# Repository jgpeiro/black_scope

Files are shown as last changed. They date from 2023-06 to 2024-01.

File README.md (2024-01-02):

# Black_scope
Low end oscilloscope based on STM32G4
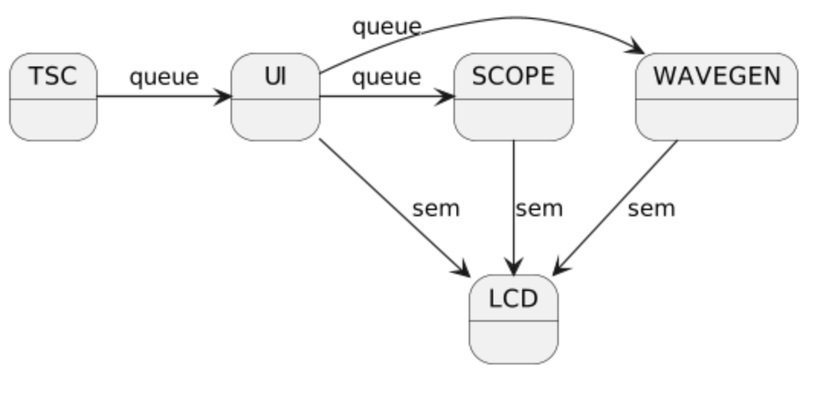
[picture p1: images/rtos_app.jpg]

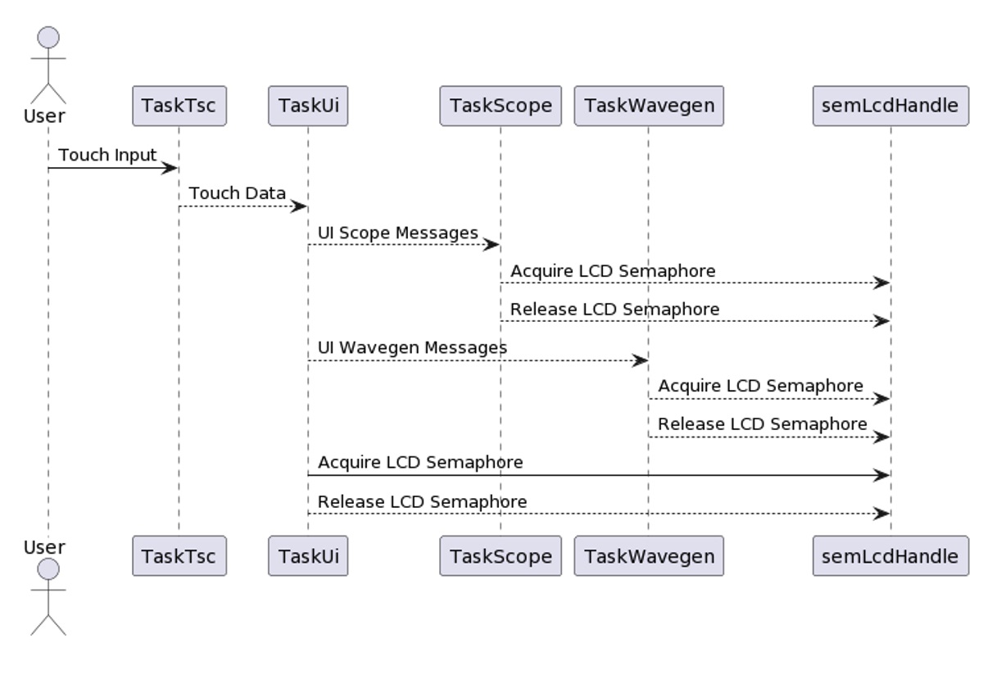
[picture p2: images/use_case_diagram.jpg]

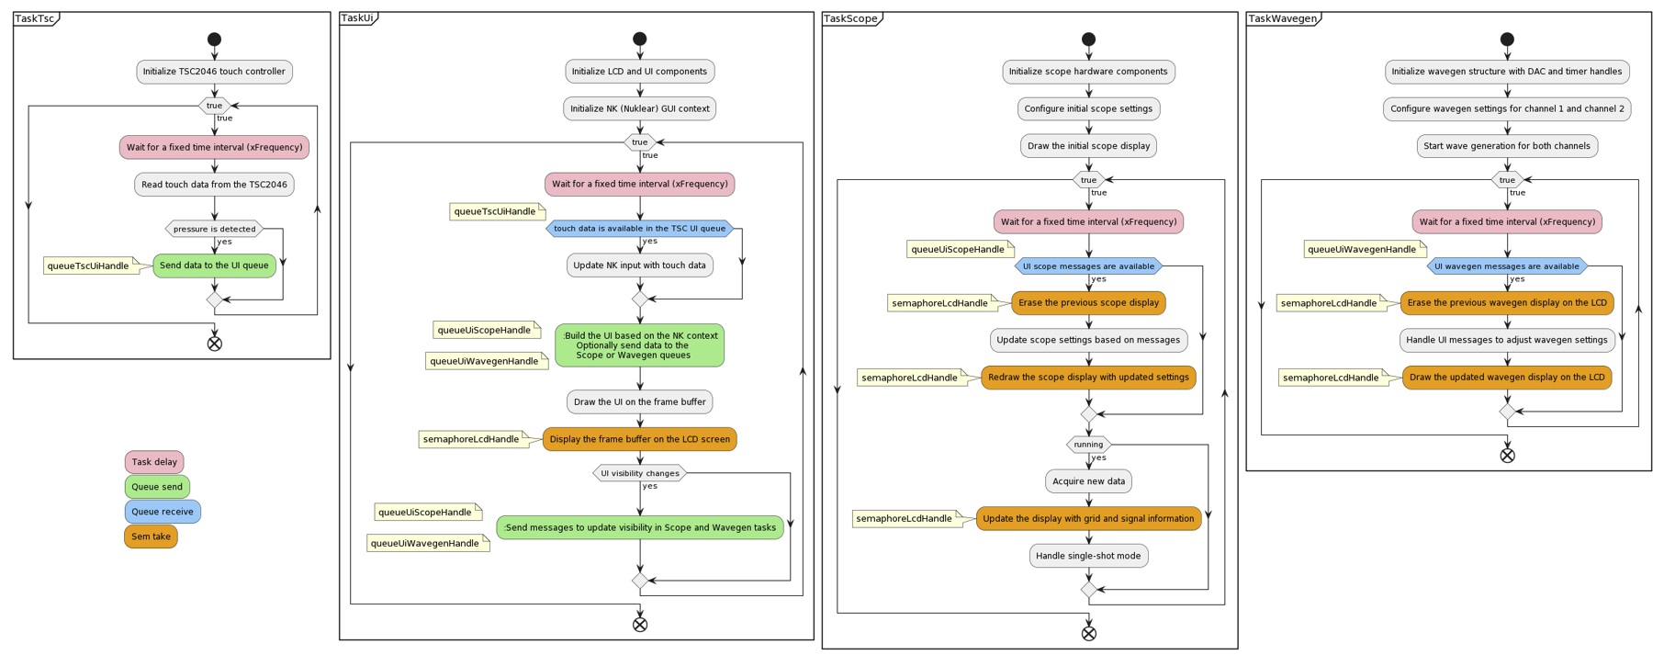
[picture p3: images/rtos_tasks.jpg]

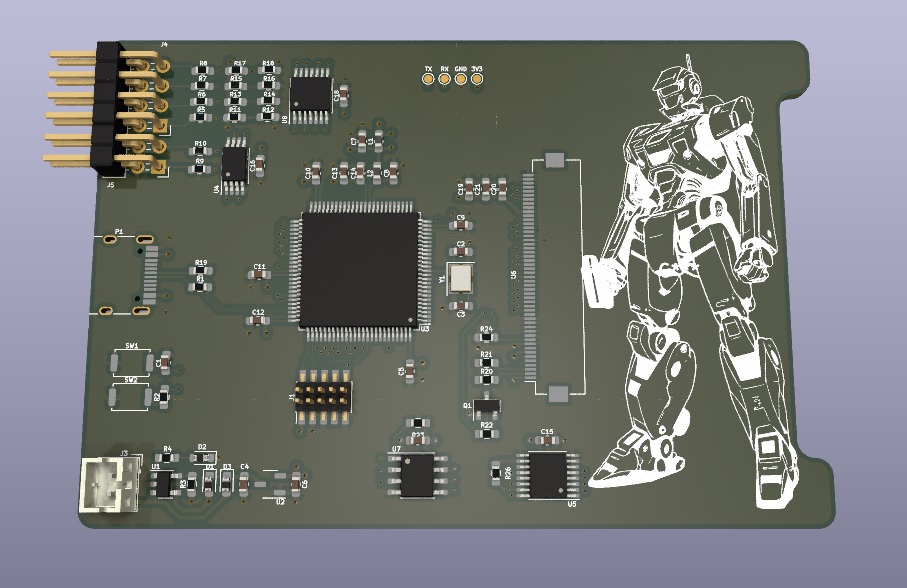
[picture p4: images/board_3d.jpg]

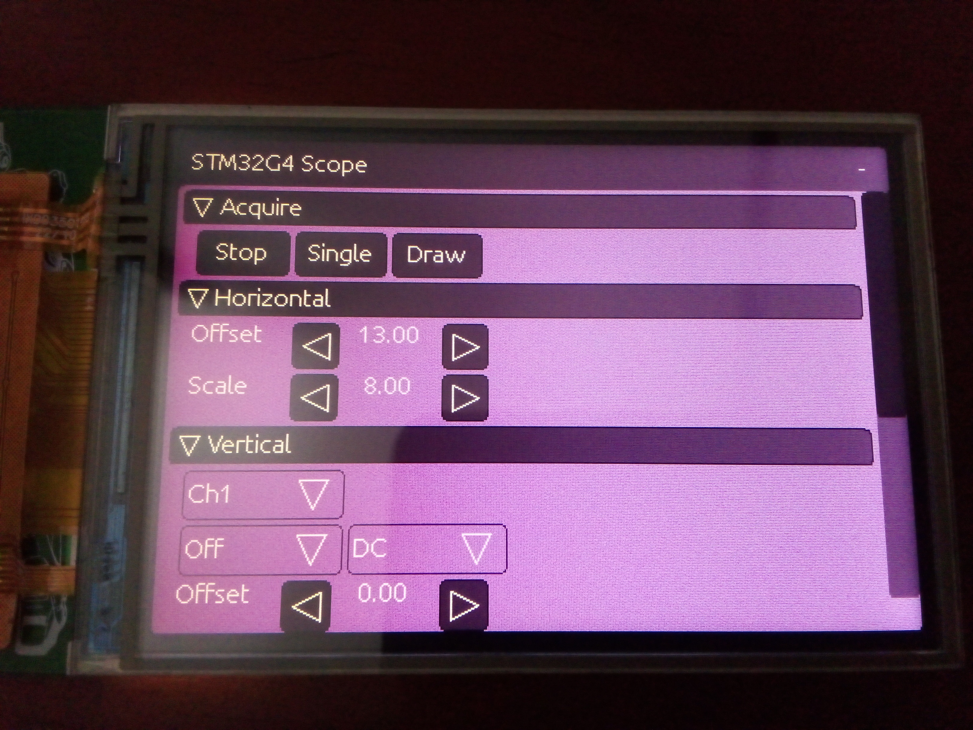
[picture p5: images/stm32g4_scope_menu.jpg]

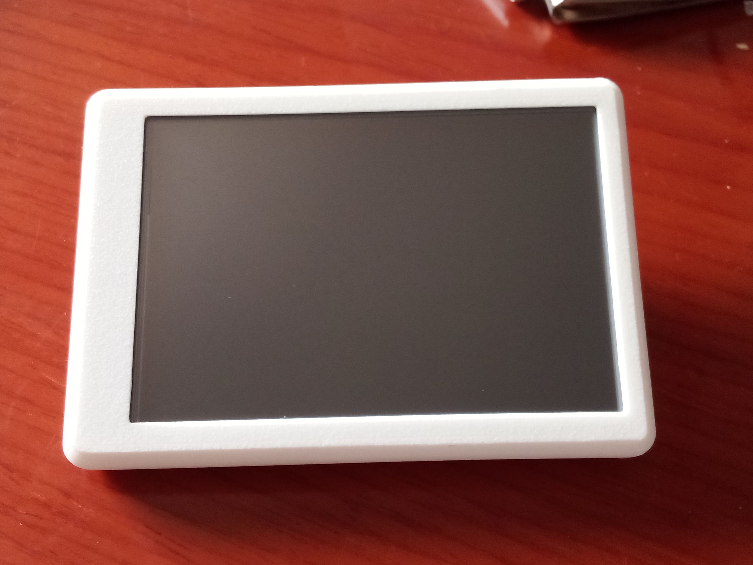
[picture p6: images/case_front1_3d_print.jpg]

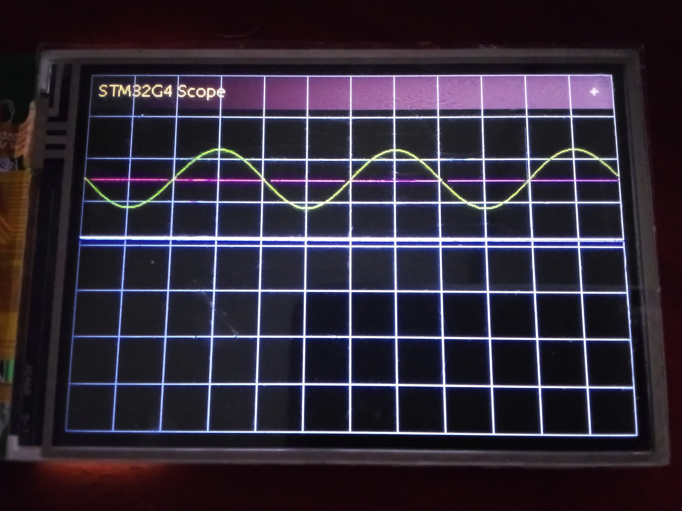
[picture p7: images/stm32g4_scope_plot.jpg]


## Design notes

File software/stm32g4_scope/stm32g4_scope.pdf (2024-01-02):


19/10/2023

stm32g4_scope Project
Configuration Report

## 1. Description

### 1.1. Project

Project Name | stm32g4_scope
Board Name | custom
Generated with: | STM32CubeMX 6.9.0
Date | 10/19/2023

### 1.2. MCU

MCU Series | STM32G4
MCU Line | STM32G4x3
MCU name | STM32G473VETx
MCU Package | LQFP100
MCU Pin number | 100

### 1.3. Core(s) information

Core(s) | ARM Cortex-M4

## 2. Pinout Configuration

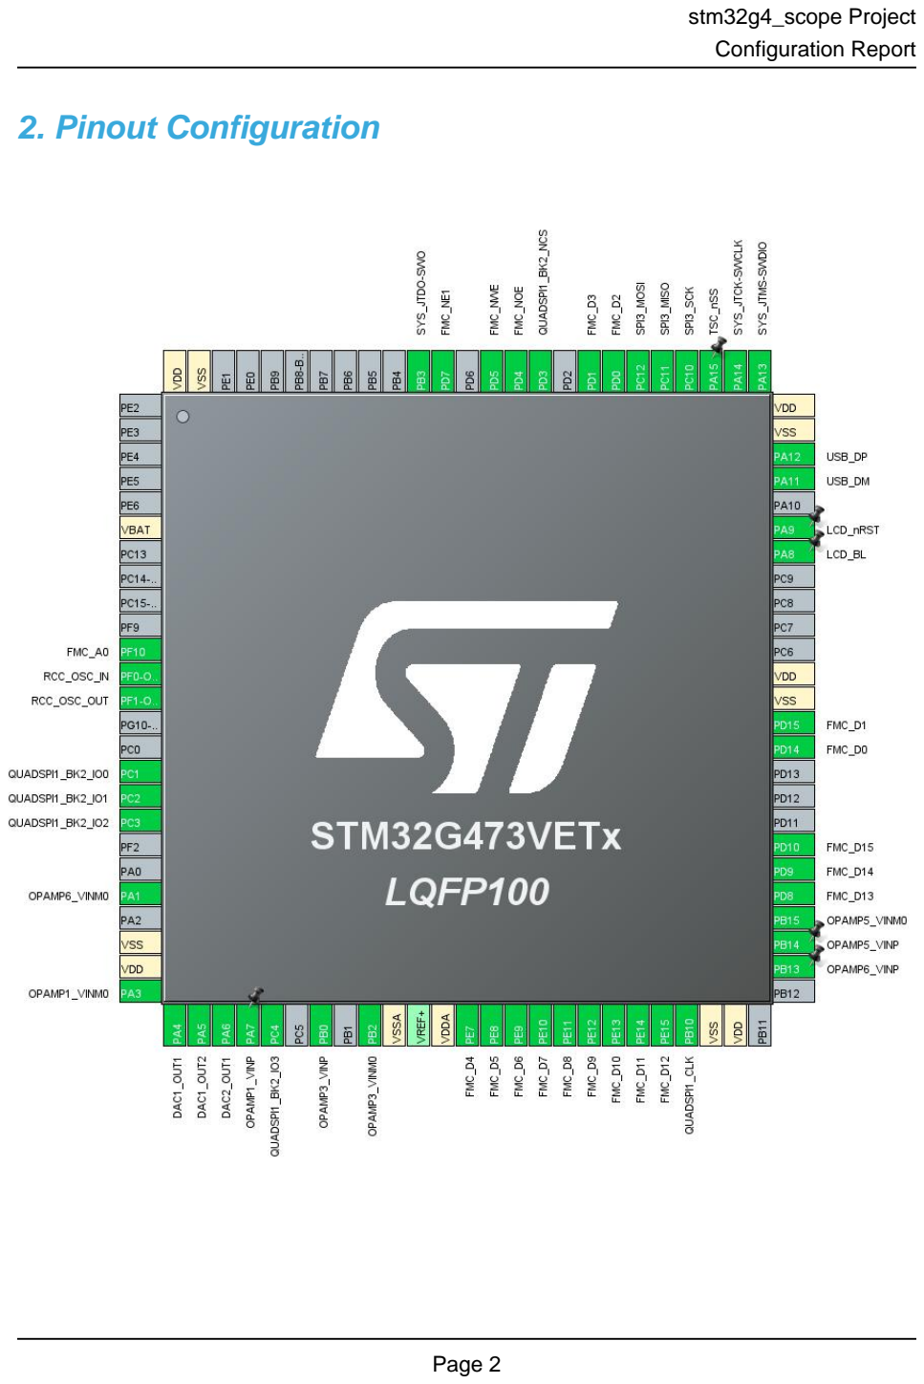
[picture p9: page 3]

## 3. Pins Configuration

Pin Number LQFP100 | Pin Name (function after reset) | Pin Type | Alternate Function(s) | Label
6 | VBAT | Power
11 | PF10 | I/O | FMC_A0
12 | PF0-OSC_IN | I/O | RCC_OSC_IN
13 | PF1-OSC_OUT | I/O | RCC_OSC_OUT
16 | PC1 | I/O | QUADSPI1_BK2_IO0
17 | PC2 | I/O | QUADSPI1_BK2_IO1
18 | PC3 | I/O | QUADSPI1_BK2_IO2
21 | PA1 | I/O | OPAMP6_VINM0
23 | VSS | Power
24 | VDD | Power
25 | PA3 | I/O | OPAMP1_VINM0
26 | PA4 | I/O | DAC1_OUT1
27 | PA5 | I/O | DAC1_OUT2
28 | PA6 | I/O | DAC2_OUT1
29 | PA7 | I/O | OPAMP1_VINP
30 | PC4 | I/O | QUADSPI1_BK2_IO3
32 | PB0 | I/O | OPAMP3_VINP
34 | PB2 | I/O | OPAMP3_VINM0
35 | VSSA | Power
37 | VDDA | Power
38 | PE7 | I/O | FMC_D4
39 | PE8 | I/O | FMC_D5
40 | PE9 | I/O | FMC_D6
41 | PE10 | I/O | FMC_D7
42 | PE11 | I/O | FMC_D8
43 | PE12 | I/O | FMC_D9
44 | PE13 | I/O | FMC_D10
45 | PE14 | I/O | FMC_D11
46 | PE15 | I/O | FMC_D12
47 | PB10 | I/O | QUADSPI1_CLK
48 | VSS | Power
49 | VDD | Power
52 | PB13 | I/O | OPAMP6_VINP
53 | PB14 | I/O | OPAMP5_VINP
54 | PB15 | I/O | OPAMP5_VINM0
55 | PD8 | I/O | FMC_D13

Pin Number LQFP100 | Pin Name (function after reset) | Pin Type | Alternate Function(s) | Label
56 | PD9 | I/O | FMC_D14
57 | PD10 | I/O | FMC_D15
61 | PD14 | I/O | FMC_D0
62 | PD15 | I/O | FMC_D1
63 | VSS | Power
64 | VDD | Power
69 | PA8 * | I/O | GPIO_Output | LCD_BL
70 | PA9 * | I/O | GPIO_Output | LCD_nRST
72 | PA11 | I/O | USB_DM
73 | PA12 | I/O | USB_DP
74 | VSS | Power
75 | VDD | Power
76 | PA13 | I/O | SYS_JTMS-SWDIO
77 | PA14 | I/O | SYS_JTCK-SWCLK
78 | PA15 * | I/O | GPIO_Output | TSC_nSS
79 | PC10 | I/O | SPI3_SCK
80 | PC11 | I/O | SPI3_MISO
81 | PC12 | I/O | SPI3_MOSI
82 | PD0 | I/O | FMC_D2
83 | PD1 | I/O | FMC_D3
85 | PD3 | I/O | QUADSPI1_BK2_NCS
86 | PD4 | I/O | FMC_NOE
87 | PD5 | I/O | FMC_NWE
89 | PD7 | I/O | FMC_NE1
90 | PB3 | I/O | SYS_JTDO-SWO
99 | VSS | Power
100 | VDD | Power

* The pin is affected with an I/O function

## 4. Clock Tree Configuration

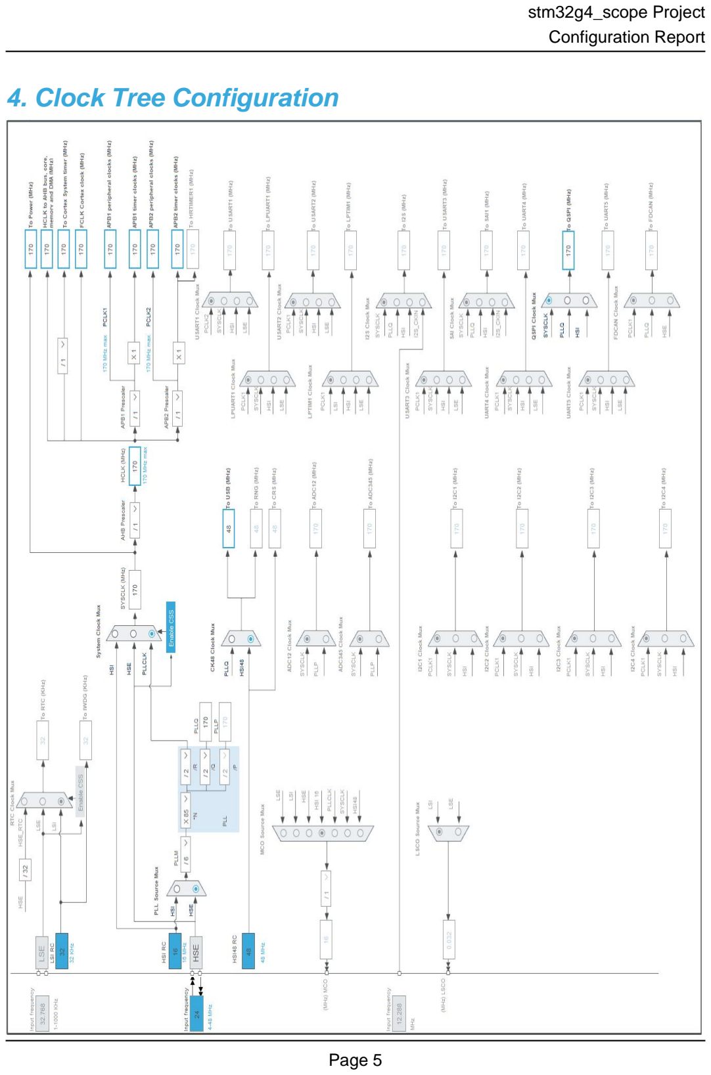
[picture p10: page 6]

## 5. Software Project

### 5.1. Project Settings

Name | Value
Project Name | stm32g4_scope
Project Folder | C:\git\black_scope\software\stm32g4_scope
Toolchain / IDE | STM32CubeIDE
Firmware Package Name and Version | STM32Cube FW_G4 V1.5.1
Application Structure | Advanced
Generate Under Root | Yes
Do not generate the main() | No
Minimum Heap Size | 0x200
Minimum Stack Size | 0x400

### 5.2. Code Generation Settings

Name | Value
STM32Cube MCU packages and embedded software | Copy only the necessary library files
Generate peripheral initialization as a pair of '.c/.h' files | Yes
Backup previously generated files when re-generating | No
Keep User Code when re-generating | Yes
Delete previously generated files when not re-generated | Yes
Set all free pins as analog (to optimize the power consumption) | No
Enable Full Assert | No

### 5.3. Advanced Settings - Generated Function Calls

Rank | Function Name | Peripheral Instance Name
1 | SystemClock_Config | RCC
2 | MX_GPIO_Init | GPIO
3 | MX_DMA_Init | DMA
4 | MX_ADC1_Init | ADC1
5 | MX_OPAMP1_Init | OPAMP1
6 | MX_DAC1_Init | DAC1
7 | MX_DAC2_Init | DAC2
8 | MX_TIM2_Init | TIM2
9 | MX_TIM3_Init | TIM3
10 | MX_FMC_Init | FMC
11 | MX_TIM4_Init | TIM4

Rank | Function Name | Peripheral Instance Name
12 | MX_ADC3_Init | ADC3
13 | MX_OPAMP3_Init | OPAMP3
14 | MX_OPAMP5_Init | OPAMP5
15 | MX_OPAMP6_Init | OPAMP6
16 | MX_ADC4_Init | ADC4
17 | MX_ADC5_Init | ADC5
18 | MX_SPI3_Init | SPI3
19 | MX_QUADSPI1_Init | QUADSPI1
20 | MX_TIM6_Init | TIM6
21 | MX_USB_Device_Init | USB_DEVICE

## 1. Power Consumption Calculator report

### 1.1. Microcontroller Selection

Series | STM32G4
Line | STM32G4x3
MCU | STM32G473VETx
Datasheet | DS12712_Rev0

### 1.2. Parameter Selection

Temperature | 25
Vdd | 3.0

### 1.3. Battery Selection

Battery | Li-SOCL2(A3400)
Capacity | 3400.0 mAh
Self Discharge | 0.08 %/month
Nominal Voltage | 3.6 V
Max Cont Current | 100.0 mA
Max Pulse Current | 200.0 mA
Cells in series | 1
Cells in parallel | 1

### 1.4. Sequence

Step | Step1 | Step2
Mode | RUN | STOP1
Vdd | 3.0 | 3.0
Voltage Source | Battery | Battery
Range | Range1-Boost | NoRange
Fetch Type | FLASH/DualBank/ART | NA
CPU Frequency | 170 MHz | 0 Hz
Clock Configuration | HSE BYP PLL | ALL CLOCKS OFF
Clock Source Frequency | 4 MHz | 0 Hz
Peripherals
Additional Cons. | 0 mA | 0 mA
Average Current | 29.5 mA | 80.5 µA
Duration | 0.1 ms | 0.9 ms
DMIPS | 213.0 | 0.0
Ta Max | 123.27 | 129.98
Category | In DS Table | In DS Table

### 1.5. Results

Sequence Time | 1 ms | Average Current | 3.02 mA
Battery Life | 1 month, 16 days, 9 hours | Average DMIPS | 212.5 DMIPS

### 1.6. Chart

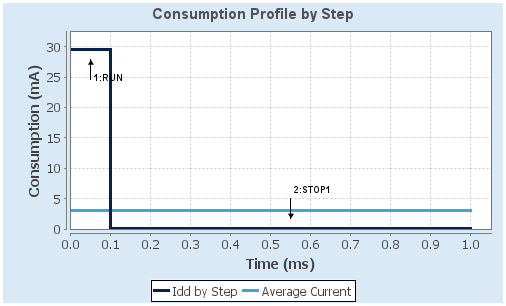
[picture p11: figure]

## 2. Peripherals and Middlewares Configuration

### 2.1. ADC1

mode: VOPAMP1 Channel
2.1.1. Parameter Settings:

ADCs_Common_Settings:

Mode | Independent mode
ADC_Settings:
Clock Prescaler | Synchronous clock mode divided by 4
Resolution | ADC 12-bit resolution
Data Alignment | Right alignment
Gain Compensation | 0
Scan Conversion Mode | Disabled
End Of Conversion Selection | End of single conversion
Low Power Auto Wait | Disabled
Continuous Conversion Mode | Disabled
Discontinuous Conversion Mode | Disabled
DMA Continuous Requests | Enabled *
Overrun behaviour | Overrun data preserved
ADC_Regular_ConversionMode:
Enable Regular Conversions | Enable
Enable Regular Oversampling | Disable
Number Of Conversion | 1
External Trigger Conversion Source | Timer 2 Trigger Out event *
External Trigger Conversion Edge | Trigger detection on the rising edge
Rank | 1
Channel | Channel Vopamp1
Sampling Time | 2.5 Cycles
Offset Number | No offset
Monitored by | Analog Watchdog 2 *
ADC_Injected_ConversionMode:
Enable Injected Conversions | Disable
Analog Watchdog 1:
Enable Analog WatchDog1 Mode | true *
Watchdog Mode | Single regular channel
Analog WatchDog Channel | Channel Vopamp1
High Threshold | 4095 *
Low Threshold | 2048+768 *
Interrupt Mode | Enabled *

Filtering | None
Analog Watchdog 2:
Enable Analog WatchDog2 Mode | true *
Watchdog Mode | Single channel *
High Threshold | 2048+768 *
Low Threshold | 0
Interrupt Mode | Enabled *
Analog Watchdog 3:
Enable Analog WatchDog3 Mode | false

### 2.2. ADC3

mode: VOPAMP3 Channel
2.2.1. Parameter Settings:

ADCs_Common_Settings:

Mode | Independent mode
ADC_Settings:
Clock Prescaler | Synchronous clock mode divided by 4
Resolution | ADC 12-bit resolution
Data Alignment | Right alignment
Gain Compensation | 0
Scan Conversion Mode | Disabled
End Of Conversion Selection | End of single conversion
Low Power Auto Wait | Disabled
Continuous Conversion Mode | Disabled
Discontinuous Conversion Mode | Disabled
DMA Continuous Requests | Enabled *
Overrun behaviour | Overrun data preserved
ADC_Regular_ConversionMode:
Enable Regular Conversions | Enable
Enable Regular Oversampling | Disable
Number Of Conversion | 1
External Trigger Conversion Source | Timer 2 Trigger Out event *
External Trigger Conversion Edge | Trigger detection on the rising edge
Rank | 1
Channel | Channel Vopamp3
Sampling Time | 2.5 Cycles
Offset Number | No offset
Monitored by

Analog Watchdog 2 *
ADC_Injected_ConversionMode:
Enable Injected Conversions | Disable
Analog Watchdog 1:
Enable Analog WatchDog1 Mode | true *
Watchdog Mode | Single regular channel
Analog WatchDog Channel | Channel Vopamp3
High Threshold | 0
Low Threshold | 0
Interrupt Mode | Enabled *
Filtering | None
Analog Watchdog 2:
Enable Analog WatchDog2 Mode | true *
Watchdog Mode | Single channel *
High Threshold | 0
Low Threshold | 0
Interrupt Mode | Enabled *
Analog Watchdog 3:
Enable Analog WatchDog3 Mode | false

### 2.3. ADC4

mode: VOPAMP6 Channel
2.3.1. Parameter Settings:

ADCs_Common_Settings:

Mode | Independent mode
ADC_Settings:
Clock Prescaler | Synchronous clock mode divided by 4
Resolution | ADC 12-bit resolution
Data Alignment | Right alignment
Gain Compensation | 0
Scan Conversion Mode | Disabled
End Of Conversion Selection | End of single conversion
Low Power Auto Wait | Disabled
Continuous Conversion Mode | Disabled
Discontinuous Conversion Mode | Disabled
DMA Continuous Requests | Enabled *
Overrun behaviour | Overrun data preserved

ADC_Regular_ConversionMode:

Enable Regular Conversions | Enable
Enable Regular Oversampling | Disable
Number Of Conversion | 1
External Trigger Conversion Source | Timer 2 Trigger Out event *
External Trigger Conversion Edge | Trigger detection on the rising edge
Rank | 1
Channel | Channel Vopamp6
Sampling Time | 2.5 Cycles
Offset Number | No offset
Monitored by | Analog Watchdog 2 *
ADC_Injected_ConversionMode:
Enable Injected Conversions | Disable
Analog Watchdog 1:
Enable Analog WatchDog1 Mode | true *
Watchdog Mode | Single regular channel
Analog WatchDog Channel | Channel Vopamp6
High Threshold | 0
Low Threshold | 0
Interrupt Mode | Enabled *
Filtering | None
Analog Watchdog 2:
Enable Analog WatchDog2 Mode | true *
Watchdog Mode | Single channel *
High Threshold | 0
Low Threshold | 0
Interrupt Mode | Enabled *
Analog Watchdog 3:
Enable Analog WatchDog3 Mode | false

### 2.4. ADC5

mode: VOPAMP5 Channel
2.4.1. Parameter Settings:

ADC_Settings:

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

Gain Compensation | 0
Scan Conversion Mode | Disabled
End Of Conversion Selection | End of single conversion
Low Power Auto Wait | Disabled
Continuous Conversion Mode | Disabled
Discontinuous Conversion Mode | Disabled
DMA Continuous Requests | Enabled *
Overrun behaviour | Overrun data preserved
ADC_Regular_ConversionMode:
Enable Regular Conversions | Enable
Enable Regular Oversampling | Disable
Number Of Conversion | 1
External Trigger Conversion Source | Timer 2 Trigger Out event *
External Trigger Conversion Edge | Trigger detection on the rising edge
Rank | 1
Channel | Channel Vopamp5
Sampling Time | 2.5 Cycles
Offset Number | No offset
Monitored by | Analog Watchdog 2 *
ADC_Injected_ConversionMode:
Enable Injected Conversions | Disable
Analog Watchdog 1:
Enable Analog WatchDog1 Mode | true *
Watchdog Mode | Single regular channel
Analog WatchDog Channel | Channel Vopamp5
High Threshold | 0
Low Threshold | 0
Interrupt Mode | Enabled *
Filtering | None
Analog Watchdog 2:
Enable Analog WatchDog2 Mode | true *
Watchdog Mode | Single channel *
High Threshold | 0
Low Threshold | 0
Interrupt Mode | Enabled *
Analog Watchdog 3:
Enable Analog WatchDog3 Mode | false

### 2.5. DAC1

OUT1 mode: Connected to external pin only OUT2 mode: Connected to external pin only
2.5.1. Parameter Settings:

DAC Out1 Settings:

Mode selected | Normal Mode
Output Buffer | Enable
DAC High Frequency | Mode Automatic
DMA Double Data | Disable
Signed Format | Disable
Trigger | Timer 4 Trigger Out event *
Trigger2 | None
Wave generation mode | Disabled
User Trimming | Factory trimming
DAC Out2 Settings:
Mode selected | Normal Mode
Output Buffer | Enable
DAC High Frequency | Mode Automatic
DMA Double Data | Disable
Signed Format | Disable
Trigger | Timer 6 Trigger Out event *
Trigger2 | None
Wave generation mode | Disabled
User Trimming | Factory trimming

### 2.6. DAC2

OUT1 mode: Connected to external pin only
2.6.1. Parameter Settings:

DAC Out1 Settings:

Mode selected | Normal Mode
Output Buffer | Enable
DAC High Frequency | Mode Automatic
DMA Double Data | Disable
Signed Format | Disable
Trigger | None
Trigger2 | None
User Trimming | Factory trimming

### 2.7. FMC

NOR Flash/PSRAM/SRAM/ROM/LCD 1 Chip Select: set
Memory type: LCD Interface
LCD Register Select: A0
Data: 16 bits
2.7.1. NOR/PSRAM 1:

NOR/PSRAM control:

Memory type | LCD Interface
Bank | Bank 1 NOR/PSRAM 1
Write operation | Enabled
Write FIFO | Enabled
Extended mode | Disabled
NOR/PSRAM timing:
Address setup time in HCLK clock cycles | 0 *
Data setup time in HCLK clock cycles | 1 *
Data hold time in HCLK clock cycles | 0
Bus turn around time in HCLK clock cycles | 0 *

### 2.8. OPAMP1

Mode: PGA Internally connected_IO0_BIAS
2.8.1. Parameter Settings:

Basic Parameters:

Power Mode | Normal
PGA Gain | 2 or -1
User Trimming | Disable

### 2.9. OPAMP3

Mode: PGA Internally connected_IO0_BIAS
2.9.1. Parameter Settings:

Basic Parameters:

Power Mode | Normal
PGA Gain | 2 or -1
User Trimming | Disable

### 2.10. OPAMP5

Mode: PGA Internally connected_IO0_BIAS
2.10.1. Parameter Settings:

Basic Parameters:

Power Mode | Normal
PGA Gain | 2 or -1
User Trimming | Disable

### 2.11. OPAMP6

Mode: PGA Internally connected_IO0_BIAS
2.11.1. Parameter Settings:

Basic Parameters:

Power Mode | Normal
PGA Gain | 2 or -1
User Trimming | Disable

### 2.12. QUADSPI1

QuadSPI Mode: Bank2 with Quad SPI Lines
2.12.1. Parameter Settings:

General Parameters:

Clock Prescaler | 6 *
Fifo Threshold | 1
Sample Shifting | No Sample Shifting
Flash Size | 23 *
Chip Select High Time | 1 Cycle
Clock Mode | Low

Flash ID | Flash ID 2
Dual Flash | Disabled

### 2.13. RCC

High Speed Clock (HSE): Crystal/Ceramic Resonator
2.13.1. Parameter Settings:

System Parameters:

VDD voltage (V) | 3.3
Instruction Cache | Enabled
Prefetch Buffer | Disabled
Data Cache | Enabled
Flash Latency(WS) | 4 WS (5 CPU cycle)
RCC Parameters:
HSI Calibration Value | 64
HSE Startup Timout Value (ms) | 100
LSE Startup Timout Value (ms) | 5000
Power Parameters:
Power Regulator Voltage Scale | Power Regulator Voltage Scale 1 boost
Peripherals Clock Configuration:
Generate the peripherals clock configuration | TRUE

### 2.14. SPI3

Mode: Full-Duplex Master
2.14.1. Parameter Settings:

Basic Parameters:

Frame Format | Motorola
Data Size | 8 Bits *
First Bit | MSB First
Clock Parameters:
Prescaler (for Baud Rate) | 128 *
Baud Rate | 1.328125 MBits/s *
Clock Polarity (CPOL) | Low
Clock Phase (CPHA) | 1 Edge
Advanced Parameters:
CRC Calculation | Disabled

NSSP Mode | Disabled *
NSS Signal Type | Software

### 2.15. SYS

Debug: Trace Asynchronous Sw
VREFBUF Mode: External voltage reference Timebase Source: TIM1

### 2.16. TIM2

Clock Source : Internal Clock
2.16.1. Parameter Settings:

Counter Settings:

Prescaler (PSC - 16 bits value) | 85-1 *
Counter Mode | Up
Dithering | Disable
Counter Period (AutoReload Register - 32 bits value ) | 2-1 *
Internal Clock Division (CKD) | No Division
auto-reload preload | Disable
Trigger Output (TRGO) Parameters:
Master/Slave Mode (MSM bit) | Disable (Trigger input effect not delayed)
Trigger Event Selection TRGO | Update Event *

### 2.17. TIM3

Clock Source : Internal Clock Channel1: Output Compare No Output
2.17.1. Parameter Settings:

Counter Settings:

Prescaler (PSC - 16 bits value) | 85-1 *
Counter Mode | Up
Dithering | Disable
Counter Period (AutoReload Register - 16 bits value ) | 512-1 *
Internal Clock Division (CKD) | No Division
auto-reload preload | Disable

Trigger Output (TRGO) Parameters:

Master/Slave Mode (MSM bit) | Disable (Trigger input effect not delayed)
Trigger Event Selection TRGO | Reset (UG bit from TIMx_EGR)
Clear Input:
Clear Input Source | Disable
Output Compare No Output Channel 1:
Mode | Frozen (used for Timing base)
Pulse (16 bits value) | 512-1 *
Output compare preload | Disable
CH Polarity | High

### 2.18. TIM4

Clock Source : Internal Clock
2.18.1. Parameter Settings:

Counter Settings:

Prescaler (PSC - 16 bits value) | 85-1 *
Counter Mode | Up
Dithering | Disable
Counter Period (AutoReload Register - 16 bits value ) | 2-1 *
Internal Clock Division (CKD) | No Division
auto-reload preload | Disable
Trigger Output (TRGO) Parameters:
Master/Slave Mode (MSM bit) | Disable (Trigger input effect not delayed)
Trigger Event Selection TRGO | Update Event *

### 2.19. TIM6

mode: Activated
2.19.1. Parameter Settings:

Counter Settings:

Prescaler (PSC - 16 bits value) | 85-1 *
Counter Mode | Up
Dithering | Disable
Counter Period (AutoReload Register - 16 bits value ) | 2-1 *
auto-reload preload | Disable

Trigger Output (TRGO) Parameters:

Trigger Event Selection | Update Event *

### 2.20. USB

mode: Device (FS)
2.20.1. Parameter Settings:

Basic Parameters:

Speed | Full Speed 12MBit/s
Physical interface | Internal Phy
Sof Enable | Disabled
Power Parameters:
Low Power | Disabled
Link Power Management | Disabled
Battery Charging | Disabled

### 2.21. FREERTOS

Interface: CMSIS_V2
2.21.1. Config parameters:

API:

FreeRTOS API | CMSIS v2
Versions:
FreeRTOS version | 10.3.1
CMSIS-RTOS version | 2.00
MPU/FPU:
ENABLE_MPU | Disabled
ENABLE_FPU | Disabled
Kernel settings:
USE_PREEMPTION | Enabled
CPU_CLOCK_HZ | SystemCoreClock
TICK_RATE_HZ | 1000
MAX_PRIORITIES | 56
MINIMAL_STACK_SIZE | 128
MAX_TASK_NAME_LEN | 16
USE_16_BIT_TICKS | Disabled
IDLE_SHOULD_YIELD | Enabled

USE_MUTEXES | Enabled
USE_RECURSIVE_MUTEXES | Enabled
USE_COUNTING_SEMAPHORES | Enabled
QUEUE_REGISTRY_SIZE | 8
USE_APPLICATION_TASK_TAG | Disabled
ENABLE_BACKWARD_COMPATIBILITY | Enabled
USE_PORT_OPTIMISED_TASK_SELECTION | Disabled
USE_TICKLESS_IDLE | Disabled
USE_TASK_NOTIFICATIONS | Enabled
RECORD_STACK_HIGH_ADDRESS | Disabled
Memory management settings:
Memory Allocation | Dynamic / Static
TOTAL_HEAP_SIZE | 16384 *
Memory Management scheme | heap_4
Hook function related definitions:
USE_IDLE_HOOK | Disabled
USE_TICK_HOOK | Disabled
USE_MALLOC_FAILED_HOOK | Disabled
USE_DAEMON_TASK_STARTUP_HOOK | Disabled
CHECK_FOR_STACK_OVERFLOW | Disabled
Run time and task stats gathering related definitions:
GENERATE_RUN_TIME_STATS | Disabled
USE_TRACE_FACILITY | Enabled
USE_STATS_FORMATTING_FUNCTIONS | Disabled
Co-routine related definitions:
USE_CO_ROUTINES | Disabled
MAX_CO_ROUTINE_PRIORITIES | 2
Software timer definitions:
USE_TIMERS | Enabled
TIMER_TASK_PRIORITY | 2
TIMER_QUEUE_LENGTH | 10
TIMER_TASK_STACK_DEPTH | 256
Interrupt nesting behaviour configuration:
LIBRARY_LOWEST_INTERRUPT_PRIORITY | 15
LIBRARY_MAX_SYSCALL_INTERRUPT_PRIORITY | 5
Added with 10.2.1 support:
MESSAGE_BUFFER_LENGTH_TYPE | size_t
USE_POSIX_ERRNO | Disabled
CMSIS-RTOS V2 flags:
USE_OS2_THREAD_SUSPEND_RESUME | Enabled
USE_OS2_THREAD_ENUMERATE | Enabled

USE_OS2_EVENTFLAGS_FROM_ISR | Enabled
USE_OS2_THREAD_FLAGS | Enabled
USE_OS2_TIMER | Enabled
USE_OS2_MUTEX | Enabled
2.21.2. Include parameters:

Include definitions:

vTaskPrioritySet | Enabled
uxTaskPriorityGet | Enabled
vTaskDelete | Enabled
vTaskCleanUpResources | Disabled
vTaskSuspend | Enabled
vTaskDelayUntil | Enabled
vTaskDelay | Enabled
xTaskGetSchedulerState | Enabled
xTaskResumeFromISR | Enabled
xQueueGetMutexHolder | Enabled
xSemaphoreGetMutexHolder | Disabled
pcTaskGetTaskName | Disabled
uxTaskGetStackHighWaterMark | Enabled
xTaskGetCurrentTaskHandle | Enabled
eTaskGetState | Enabled
xEventGroupSetBitFromISR | Disabled
xTimerPendFunctionCall | Enabled
xTaskAbortDelay | Disabled
xTaskGetHandle | Disabled
uxTaskGetStackHighWaterMark2 | Disabled
2.21.3. Advanced settings:

Newlib settings (see parameter description first):

USE_NEWLIB_REENTRANT | Enabled *
Project settings (see parameter description first):
Use FW pack heap file | Enabled

### 2.22. USB_DEVICE

Class For FS IP: Communication Device Class (Virtual Port Com)

2.22.1. Parameter Settings:

Basic Parameters:

USBD_MAX_NUM_INTERFACES (Maximum number of supported interfaces) | 1
USBD_MAX_NUM_CONFIGURATION (Maximum number of supported configuration) | 1
USBD_MAX_STR_DESC_SIZ (Maximum size for the string descriptors) | 512
USBD_SELF_POWERED (Enabled self power) | Enabled
USBD_DEBUG_LEVEL (USBD Debug Level) | 0: No debug message
USBD_LPM_ENABLED (Link Power Management) | 1: Link Power Management supported
Class Parameters:
USB CDC Rx Buffer Size | 2048
USB CDC Tx Buffer Size | 2048
2.22.2. Device Descriptor:

Device Descriptor:

VID (Vendor IDentifier) | 1155
LANGID_STRING (Language Identifier) | English(United States)
MANUFACTURER_STRING (Manufacturer Identifier) | STMicroelectronics
Device Descriptor FS:
PID (Product IDentifier) | 22336
PRODUCT_STRING (Product Identifier) | STM32 Virtual ComPort
CONFIGURATION_STRING (Configuration Identifier) | CDC Config
INTERFACE_STRING (Interface Identifier) | CDC Interface

* User modified value

## 3. System Configuration

### 3.1. GPIO configuration

IP | Pin | Signal | GPIO mode | GPIO pull/up pull down

Max
Speed

User Label

DAC1 | PA4 | DAC1_OUT1 | Analog mode | No pull-up and no pull-down | n/a
| PA5 | DAC1_OUT2 | Analog mode | No pull-up and no pull-down | n/a
DAC2 | PA6 | DAC2_OUT1 | Analog mode | No pull-up and no pull-down | n/a
FMC | PF10 | FMC_A0 | Alternate Function Push Pull | No pull-up and no pull-down | Very High
| PE7 | FMC_D4 | Alternate Function Push Pull | No pull-up and no pull-down | Very High
| PE8 | FMC_D5 | Alternate Function Push Pull | No pull-up and no pull-down | Very High
| PE9 | FMC_D6 | Alternate Function Push Pull | No pull-up and no pull-down | Very High
| PE10 | FMC_D7 | Alternate Function Push Pull | No pull-up and no pull-down | Very High
| PE11 | FMC_D8 | Alternate Function Push Pull | No pull-up and no pull-down | Very High
| PE12 | FMC_D9 | Alternate Function Push Pull | No pull-up and no pull-down | Very High
| PE13 | FMC_D10 | Alternate Function Push Pull | No pull-up and no pull-down | Very High
| PE14 | FMC_D11 | Alternate Function Push Pull | No pull-up and no pull-down | Very High
| PE15 | FMC_D12 | Alternate Function Push Pull | No pull-up and no pull-down | Very High
| PD8 | FMC_D13 | Alternate Function Push Pull | No pull-up and no pull-down | Very High
| PD9 | FMC_D14 | Alternate Function Push Pull | No pull-up and no pull-down | Very High
| PD10 | FMC_D15 | Alternate Function Push Pull | No pull-up and no pull-down | Very High
| PD14 | FMC_D0 | Alternate Function Push Pull | No pull-up and no pull-down | Very High
| PD15 | FMC_D1 | Alternate Function Push Pull | No pull-up and no pull-down | Very High
| PD0 | FMC_D2 | Alternate Function Push Pull | No pull-up and no pull-down | Very High
| PD1 | FMC_D3 | Alternate Function Push Pull | No pull-up and no pull-down | Very High
| PD4 | FMC_NOE | Alternate Function Push Pull | No pull-up and no pull-down | Very High
| PD5 | FMC_NWE | Alternate Function Push Pull | No pull-up and no pull-down | Very High
| PD7 | FMC_NE1 | Alternate Function Push Pull | No pull-up and no pull-down | Very High
OPAMP1 | PA3 | OPAMP1_VINM0 | Analog mode | No pull-up and no pull-down | n/a
| PA7 | OPAMP1_VINP | Analog mode | No pull-up and no pull-down | n/a
OPAMP3 | PB0 | OPAMP3_VINP | Analog mode | No pull-up and no pull-down | n/a
| PB2 | OPAMP3_VINM0 | Analog mode | No pull-up and no pull-down | n/a
OPAMP5 | PB14 | OPAMP5_VINP | Analog mode | No pull-up and no pull-down | n/a
| PB15 | OPAMP5_VINM0 | Analog mode | No pull-up and no pull-down | n/a
OPAMP6 | PA1 | OPAMP6_VINM0 | Analog mode | No pull-up and no pull-down | n/a
| PB13 | OPAMP6_VINP | Analog mode | No pull-up and no pull-down | n/a
QUADSPI1 | PC1 | QUADSPI1_BK2 _IO0 | Alternate Function Push Pull | No pull-up and no pull-down | Very High
*
| PC2 | QUADSPI1_BK2 _IO1 | Alternate Function Push Pull | No pull-up and no pull-down | Very High
*
| PC3 | QUADSPI1_BK2 | Alternate Function Push Pull | No pull-up and no pull-down | Very High

IP | Pin | Signal | GPIO mode | GPIO pull/up pull down | Max Speed | User Label
| | _IO2 | | | *
| PC4 | QUADSPI1_BK2 _IO3 | Alternate Function Push Pull | No pull-up and no pull-down | Very High *
| PB10 | QUADSPI1_CLK | Alternate Function Push Pull | No pull-up and no pull-down | Very High *
| PD3 | QUADSPI1_BK2 _NCS | Alternate Function Push Pull | No pull-up and no pull-down | Very High *
RCC | PF0-OSC_IN | RCC_OSC_IN | n/a | n/a | n/a
| PF1-OSC_OUT | RCC_OSC_OUT | n/a | n/a | n/a
SPI3 | PC10 | SPI3_SCK | Alternate Function Push Pull | No pull-up and no pull-down | Low
| PC11 | SPI3_MISO | Alternate Function Push Pull | No pull-up and no pull-down | Low
| PC12 | SPI3_MOSI | Alternate Function Push Pull | No pull-up and no pull-down | Low
SYS | PA13 | SYS_JTMS-SWDIO | n/a | n/a | n/a
| PA14 | SYS_JTCK-SWCLK | n/a | n/a | n/a
| PB3 | SYS_JTDO-SWO | n/a | n/a | n/a
USB | PA11 | USB_DM | n/a | n/a | n/a
| PA12 | USB_DP | n/a | n/a | n/a
GPIO | PA8 | GPIO_Output | Output Push Pull | No pull-up and no pull-down | Low | LCD_BL
| PA9 | GPIO_Output | Output Push Pull | No pull-up and no pull-down | Low | LCD_nRST
| PA15 | GPIO_Output | Output Push Pull | No pull-up and no pull-down | Low | TSC_nSS

### 3.2. DMA configuration

DMA request | Stream | Direction | Priority
ADC1 | DMA1_Channel1 | Peripheral To Memory | Low
DAC1_CH1 | DMA2_Channel1 | Memory To Peripheral | Low
ADC3 | DMA1_Channel2 | Peripheral To Memory | Low
ADC4 | DMA1_Channel3 | Peripheral To Memory | Low
ADC5 | DMA1_Channel4 | Peripheral To Memory | Low
DAC1_CH2 | DMA2_Channel2 | Memory To Peripheral | Low
QUADSPI | DMA1_Channel5 | Peripheral To Memory | Low

ADC1: DMA1_Channel1 DMA request Settings:

Mode: | Circular *
Peripheral Increment: | Disable
Memory Increment: | Enable *
Peripheral Data Width: | Half Word
Memory Data Width: | Half Word

DAC1_CH1: DMA2_Channel1 DMA request Settings:

Mode: | Circular *
Peripheral Increment: | Disable
Memory Increment: | Enable *
Peripheral Data Width: | Word *
Memory Data Width: | Half Word

ADC3: DMA1_Channel2 DMA request Settings:

Mode: | Circular *
Peripheral Increment: | Disable
Memory Increment: | Enable *
Peripheral Data Width: | Half Word
Memory Data Width: | Half Word

ADC4: DMA1_Channel3 DMA request Settings:

Mode: | Circular *

Peripheral Increment: | Disable
Memory Increment: | Enable *
Peripheral Data Width: | Half Word
Memory Data Width: | Half Word

ADC5: DMA1_Channel4 DMA request Settings:

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

DAC1_CH2: DMA2_Channel2 DMA request Settings:

Mode: | Circular *
Peripheral Increment: | Disable
Memory Increment: | Enable *
Peripheral Data Width: | Word *
Memory Data Width: | Half Word

QUADSPI: DMA1_Channel5 DMA request Settings:

Mode: | Normal
Peripheral Increment: | Disable
Memory Increment: | Enable *
Peripheral Data Width: | Byte
Memory Data Width: | Byte

### 3.3. NVIC configuration

3.3.1. NVIC
Interrupt Table | Enable | Preenmption Priority | SubPriority
Non maskable interrupt | true | 0 | 0
Hard fault interrupt | true | 0 | 0
Memory management fault | true | 0 | 0
Prefetch fault, memory access fault | true | 0 | 0
Undefined instruction or illegal state | true | 0 | 0
System service call via SWI instruction | true | 0 | 0
Debug monitor | true | 0 | 0
Pendable request for system service | true | 15 | 0
System tick timer | true | 15 | 0
DMA1 channel1 global interrupt | true | 5 | 0
DMA1 channel2 global interrupt | true | 5 | 0
DMA1 channel3 global interrupt | true | 5 | 0
DMA1 channel4 global interrupt | true | 5 | 0
DMA1 channel5 global interrupt | true | 5 | 0
ADC1 and ADC2 global interrupt | true | 5 | 0
USB low priority interrupt remap | true | 5 | 0
TIM1 update interrupt and TIM16 global interrupt | true | 15 | 0
TIM3 global interrupt | true | 5 | 0
ADC3 global interrupt | true | 5 | 0
DMA2 channel1 global interrupt | true | 5 | 0
DMA2 channel2 global interrupt | true | 5 | 0
ADC4 global interrupt | true | 5 | 0
ADC5 global interrupt | true | 5 | 0
QUADSPI global interrupt | true | 5 | 0
PVD/PVM1/PVM2/PVM3/PVM4 interrupts through EXTI lines 16/38/39/40/41 | unused
Flash global interrupt | unused
RCC global interrupt | unused
USB high priority interrupt remap | unused
TIM2 global interrupt | unused
TIM4 global interrupt | unused
SPI3 global interrupt | unused
TIM6 global interrupt, DAC1 and DAC3 channel underrun error interrupts | unused
TIM7 global interrupt, DAC2 and DAC4 channel underrun error interrupts | unused
FPU global interrupt | unused

3.3.2. NVIC Code generation
Enabled interrupt Table | Select for init sequence ordering | Generate IRQ handler | Call HAL handler
Non maskable interrupt | false | true | false
Hard fault interrupt | false | true | false
Memory management fault | false | true | false
Prefetch fault, memory access fault | false | true | false
Undefined instruction or illegal state | false | true | false
System service call via SWI instruction | false | false | false
Debug monitor | false | true | false
Pendable request for system service | false | false | false
System tick timer | false | false | true
DMA1 channel1 global interrupt | false | true | true
DMA1 channel2 global interrupt | false | true | true
DMA1 channel3 global interrupt | false | true | true
DMA1 channel4 global interrupt | false | true | true
DMA1 channel5 global interrupt | false | true | true
ADC1 and ADC2 global interrupt | false | true | true
USB low priority interrupt remap | false | true | true
TIM1 update interrupt and TIM16 global interrupt | false | true | true
TIM3 global interrupt | false | true | true
ADC3 global interrupt | false | true | true
DMA2 channel1 global interrupt | false | true | true
DMA2 channel2 global interrupt | false | true | true
ADC4 global interrupt | false | true | true
ADC5 global interrupt | false | true | true
QUADSPI global interrupt | false | true | true

* User modified value

## 4. System Views

4.1. Category view
4.1.1. Current

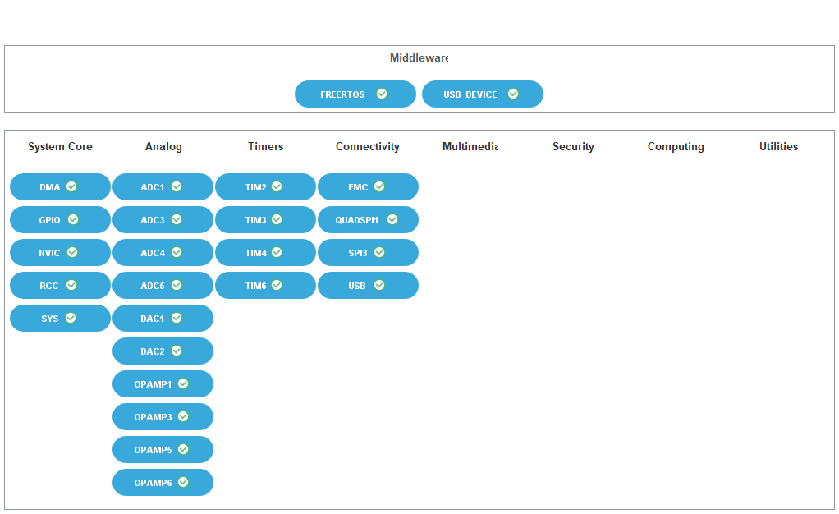
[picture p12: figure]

## 5. Docs & Resources

Type | Link
BSDL files | https://www.st.com/resource/en/bsdl_model/stm32g4_bsdl.zip
IBIS models | https://www.st.com/resource/en/ibis_model/stm32g4_ibis.zip
System View Description | https://www.st.com/resource/en/svd/stm32g4_svd.zip
Presentations | https://www.st.com/resource/en/product_presentation/microcontrollers_stm32g4_series_product_overview.pdf
Presentations | https://www.st.com/resource/en/product_presentation/stm32-stm8_embedded_software_solutions.pdf
Presentations | https://www.st.com/resource/en/product_presentation/stm32_eval-tools_portfolio.pdf
Presentations | https://www.st.com/resource/en/product_presentation/stm32_stm8_functi onal-safety-packages.pdf
Presentations | https://www.st.com/resource/en/product_presentation/stm32-usb-c-pd-solutions-presentation.pdf
Presentations | https://www.st.com/resource/en/product_presentation/stm32-stm8_software_development_tools.pdf
Brochures | https://www.st.com/resource/en/brochure/products-and-solutions-for-plcs-and-smart-i-os.pdf
Flyers | https://www.st.com/resource/en/flyer/flstm32g4.pdf
Flyers | https://www.st.com/resource/en/flyer/flstm32nucleo.pdf
Flyers | https://www.st.com/resource/en/flyer/flstm32trust.pdf
Flyers | https://www.st.com/resource/en/flyer/fldpstpfc11120.pdf
Application Notes | https://www.st.com/resource/en/application_note/an1181-electrostatic-discharge-sensitivity-measurement-stmicroelectronics.pdf
Application Notes | https://www.st.com/resource/en/application_note/an1709-emc-design-guide-for-stm8-stm32-and-legacy-mcus-stmicroelectronics.pdf
Application Notes | https://www.st.com/resource/en/application_note/an2606-stm32-microcontroller-system-memory-boot-mode-stmicroelectronics.pdf
Application Notes | https://www.st.com/resource/en/application_note/an2639-soldering-

| recommendations-and-package-information-for-leadfree-ecopack-mcus-and-mpus-stmicroelectronics.pdf
Application Notes | https://www.st.com/resource/en/application_note/an2834-how-to-get-the-best-adc-accuracy-in-stm32-microcontrollers-stmicroelectronics.pdf
Application Notes | https://www.st.com/resource/en/application_note/an3126-audio-and-waveform-generation-using-the-dac-in-stm32-products-stmicroelectronics.pdf
Application Notes | https://www.st.com/resource/en/application_note/an3155-usart-protocol-used-in-the-stm32-bootloader-stmicroelectronics.pdf
Application Notes | https://www.st.com/resource/en/application_note/an3156-usb-dfu-protocol-used-in-the-stm32-bootloader-stmicroelectronics.pdf
Application Notes | https://www.st.com/resource/en/application_note/an4013-stm32-crossseries-timer-overview-stmicroelectronics.pdf
Application Notes | https://www.st.com/resource/en/application_note/an4221-i2c-protocol-used-in-the-stm32-bootloader-stmicroelectronics.pdf
Application Notes | https://www.st.com/resource/en/application_note/an4229-how-to-implement-a-vocoder-solution-using-stm32-microcontrollers-stmicroelectronics.pdf
Application Notes | https://www.st.com/resource/en/application_note/an4232-getting-started-with-analog-comparators-for-stm32f3-series-and-stm32g4-series-devices-stmicroelectronics.pdf
Application Notes | https://www.st.com/resource/en/application_note/an4277-using-stm32-device-pwm-shutdown-features-for-motor-control-and-digital-power-conversion-stmicroelectronics.pdf
Application Notes | https://www.st.com/resource/en/application_note/an4286-spi-protocol-used-in-the-stm32-bootloader-stmicroelectronics.pdf
Application Notes | https://www.st.com/resource/en/application_note/an4296-use-stm32f3stm32g4-ccm-sram-with-iar-embedded-workbench-keil-mdkarm-stmicroelectronics-stm32cubeide-and-other-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
Application Notes | https://www.st.com/resource/en/application_note/an4566-extending-the-dac-performance-of-stm32-microcontrollers-stmicroelectronics.pdf
Application Notes | https://www.st.com/resource/en/application_note/an4635-minimization-of-

| power-consumption-using-lpuart-for-stm32-microcontrollers-stmicroelectronics.pdf
Application Notes | https://www.st.com/resource/en/application_note/an4655-virtually-increasing-the-number-of-serial-communication-peripherals-in-stm32-applications-stmicroelectronics.p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
Application Notes | https://www.st.com/resource/en/application_note/an4750-handling-of-soft-errors-in-stm32-applications-stmicroelectronics.pdf
Application Notes | https://www.st.com/resource/en/application_note/an4759-using-the-hardware-realtime-clock-rtc-and-the-tamper-management-unit-tamp-with-stm32-microcontrollers-stmicroe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
Application Notes | https://www.st.com/resource/en/application_note/an4776-generalpurpose-timer-cookbook-for-stm32-microcontrollers-stmicroelectronics.pdf
Application Notes | https://www.st.com/resource/en/application_note/an4803-highspeed-si-simulations-using-ibis-and-boardlevel-simulations-using-hyperlynx-si-on-stm32-mcus-and-mpus-stmic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
Application Notes | https://www.st.com/resource/en/application_note/an4894-eeprom-emulation-techniques-and-software-for-stm32-microcontrollers-stmicroelectronics.pdf
Application Notes | https://www.st.com/resource/en/application_note/an4989-stm32-microcontroller-debug-toolbox-stmicroelectronics.pdf
Application Notes | https://www.st.com/resource/en/application_note/an5027-interfacing-pdm-digital-microphones-using-stm32-mcus-and-mpus-stmicroelectronics.pdf
Application Notes | https://www.st.com/resource/en/application_note/an5036-thermal-management-guidelines-for-stm32-applications-stmicroelectronics.pdf
Application Notes | https://www.st.com/resource/en/application_note/an5093-getting-started-with-stm32g4-series--hardware-development-boards-stmicroelectronics.pdf
Application Notes | https://www.st.com/resource/en/application_note/an5224-stm32-dmamux-the-dma-request-router-stmicroelectronics.pdf
Application Notes | https://www.st.com/resource/en/application_note/an5225-usb-typec-power-delivery-using-stm32-mcus-and-mpus-stmicroelectronics.pdf
Application Notes | https://www.st.com/resource/en/application_note/an5306-operational-amplifier-opamp-usage-in-stm32g4-series-stmicroelectronics.pdf

Application Notes | https://www.st.com/resource/en/application_note/an5310-guideline-for-using-analog-features-of-stm32g4-series-versus-stm32f3-series-devices-stmicroelectronics.pdf
Application Notes | https://www.st.com/resource/en/application_note/an5315-stm32cube-firmware-examples-for-stm32g4-series-stmicroelectronics.pdf
Application Notes | https://www.st.com/resource/en/application_note/an5346-stm32g4-adc-use-tips-and-recommendations-stmicroelectronics.pdf
Application Notes | https://www.st.com/resource/en/application_note/an5405-fdcan-protocol-used-in-the-stm32-bootloader-stmicroelectronics.pdf
Application Notes | https://www.st.com/resource/en/application_note/an5543-enhanced-methods-to-handle-spi-communication-on-stm32-devices-stmicroelectronics.pdf
Application Notes | https://www.st.com/resource/en/application_note/an5690-vrefbuf-peripheral-applications-and-trimming-technique-stmicroelectronics.pdf
Application Notes | https://www.st.com/resource/en/application_note/an5738-stm32g4-series-lifetime-estimates-stmicroelectronics.pdf
Application Notes | https://www.st.com/resource/en/application_note/an4760-quadspi-interface-on-stm32-microcontrollers-and-microprocessors--stmicroelectronics.pdf
Application Notes | https://www.st.com/resource/en/application_note/an4899-stm32-microcontroller-gpio-hardware-settings-and-lowpower-consumption-stmicroelectronics.pdf
Application Notes | https://www.st.com/resource/en/application_note/an5612-esd-protection-of-stm32-mcus-and-mpus-stmicroelectronics.pdf
Application Notes | https://www.st.com/resource/en/application_note/an5156-introduction-to-stm32-microcontrollers-security-stmicroelectronics.pdf
Application Notes | https://www.st.com/resource/en/application_note/an2548-using-the-stm32f0f1f3cxgxlx-series-dma-controller-stmicroelectronics.pdf
Application Notes | https://www.st.com/resource/en/application_note/an4991-how-to-wake-up-an-stm32-microcontroller-from-lowpower-mode-with-the-usart-or-the-lpuart-stmicroelectronics.pdf
Application Notes | https://www.st.com/resource/en/application_note/an4838-introduction-to- memory-protection-unit-management-on-stm32-mcus-

| stmicroelectronics.pdf
Application Notes | https://www.st.com/resource/en/application_note/an5325-how-to-use-the-cordic-to-perform-mathematical-functions-on-stm32-mcus-stmicroelectronics.pdf
Application Notes | https://www.st.com/resource/en/application_note/an5348-introduction-to-fdcan-peripherals-for-stm32-product-classes-stmicroelectronics.pdf
Application Notes | https://www.st.com/resource/en/application_note/an4230-random-number-generation-validation-using-nist-statistical-test-suite-for-stm32-microcontrollers-stmicroelectr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
Application Notes for related Tools & Software | https://www.st.com/resource/en/application_note/an1202_freertos_guide-freertos-guide-stmicroelectronics.pdf
Application Notes for related Tools & Software | https://www.st.com/resource/en/application_note/an1602_semihosting_in_truestudio-how-to-do-semihosting-in-truestudio-stmicroelectronics.pdf
Application Notes for related Tools & Software | https://www.st.com/resource/en/application_note/an1801_stm32cubeprogrammer_in_truestudio-installing-stm32cubeprogrammer-in-truestudio-stmicroelectronics.pdf
Application Notes for related Tools & Software | https://www.st.com/resource/en/application_note/atollic_editing_keyboard_shortcuts-atollic-editing-keyboard-shortcuts-stmicroelectronics.pdf
Application Notes for related Tools & Software | https://www.st.com/resource/en/application_note/iar_to_atollic_truestudio_migration_guide-truestudio-for-arm-migration-guide-iar-embedded-workbench-to-truestudio-stm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
Application Notes for related Tools & Software | https://www.st.com/resource/en/application_note/stm32cubemx_installation_in_truestudio-stm32cubemx-installation-in-truestudio-stmicroelectronics.pdf
Application Notes for related Tools & Software | https://www.st.com/resource/en/application_note/an4435-guidelines-for-obtaining-ulcsaiec-607301603351-class-b-certification-in-any-stm32-application-stmicroelectroni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
Application Notes for related Tools & Software | https://www.st.com/resource/en/application_note/an4635-minimization-of-power-consumption-using-lpuart-for-stm32-microcontrollers-stmicroelectronics.pdf
Application Notes | https://www.st.com/resource/en/application_note/an4657-stm32-

for related Tools & Software | inapplication-programming-iap-using-the-usart-stmicroelectronics.pdf
Application Notes for related Tools & Software | https://www.st.com/resource/en/application_note/an4759-using-the-hardware-realtime-clock-rtc-and-the-tamper-management-unit-tamp-with-stm32-microcontrollers-stmicroe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
Application Notes for related Tools & Software | https://www.st.com/resource/en/application_note/an4841-digital-signal-processing-for-stm32-microcontrollers-using-cmsis-stmicroelectronics.pdf
Application Notes for related Tools & Software | https://www.st.com/resource/en/application_note/an5054-secure-programming-using-stm32cubeprogrammer-stmicroelectronics.pdf
Application Notes for related Tools & Software | https://www.st.com/resource/en/application_note/an5056-integration-guide-for-the-xcubesbsfu-stm32cube-expansion-package-stmicroelectronics.pdf
Application Notes for related Tools & Software | https://www.st.com/resource/en/application_note/an5305-digital-filter-implementation-with-the-fmac-using-stm32cubeg4-mcu-package-stmicroelectronics.pdf
Application Notes for related Tools & Software | https://www.st.com/resource/en/application_note/an5315-stm32cube-firmware-examples-for-stm32g4-series-stmicroelectronics.pdf
Application Notes for related Tools & Software | https://www.st.com/resource/en/application_note/an5345-highbrightness-rgb-led-control-using-the-bg474edpow1-discovery-kit-stmicroelectronics.pdf
Application Notes for related Tools & Software | https://www.st.com/resource/en/application_note/an5360-getting-started-with-projects-based-on-the-stm32mp1-series-in-stm32cubeide-stmicroelectronics.pdf
Application Notes for related Tools & Software | https://www.st.com/resource/en/application_note/an5361-getting-started-with-projects-based-on-dualcore-stm32h7-microcontrollers-in-stm32cubeide-stmicroelectronics.pd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
Application Notes for related Tools & Software | https://www.st.com/resource/en/application_note/an5394-getting-started-with-projects-based-on-the-stm32l5-series-in-stm32cubeide-stmicroelectronics.pdf

Application Notes
for related Tools

https://www.st.com/resource/en/application_note/an5418-how-to-build-asimple-usbpd-sink-application-with-stm32cubemx-stmicroelectronics.pdf

& Software
Application Notes for related Tools & Software | https://www.st.com/resource/en/application_note/an5426-migrating-graphics-middleware-projects-from-stm32cubemx-540-to-stm32cubemx-550-stmicroelectronics.pdf
Application Notes for related Tools & Software | https://www.st.com/resource/en/application_note/an5464-position-control-of-a-threephase-permanent-magnet-motor-using-xcubemcsdk-or-xcubemcsdkful-stmicroelectronics.p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
Application Notes for related Tools & Software | https://www.st.com/resource/en/application_note/an5496-buck-voltage-mode-with-the-bg474edpow1-discovery-kit-stmicroelectronics.pdf
Application Notes for related Tools & Software | https://www.st.com/resource/en/application_note/an5497-buck-current-mode-with-the-bg474edpow1-discovery-kit-stmicroelectronics.pdf
Application Notes for related Tools & Software | https://www.st.com/resource/en/application_note/an5564-getting-started-with-projects-based-on-dualcore-stm32wl-microcontrollers-in-stm32cubeide-stmicroelectronics.pd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
Application Notes for related Tools & Software | https://www.st.com/resource/en/application_note/an5698-adapting-the-xcubestl-functional-safety-package-for-stm32-iec-61508-compliant-to-other-safety-standards-stmicr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
Application Notes for related Tools & Software | https://www.st.com/resource/en/application_note/an5731-stm32cubemx-and-stm32cubeide-threadsafe-solution-stmicroelectronics.pdf
Application Notes for related Tools & Software | https://www.st.com/resource/en/application_note/an5785-boost-voltage-mode-on-bg474edpow1-discovery-kit-stmicroelectronics.pdf
Application Notes for related Tools & Software | https://www.st.com/resource/en/application_note/an5788-stm32-digital-power-pid-and-iir-filters-for-smps-control-design-and-comparison-on-bg414edpow1-discovery-kit-st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
Application Notes for related Tools & Software | https://www.st.com/resource/en/application_note/an4502-stm32-smbuspmbus-expansion-package-for-stm32cube-stmicroelectronics.pdf
Errata Sheets | https://www.st.com/resource/en/errata_sheet/es0430-stm32g471xx473xx474xx483xx484xx-device-errata-stmicroelectronics.pdf
Datasheet | https://www.st.com/resource/en/datasheet/dm00528822.pdf

Programming Manuals | https://www.st.com/resource/en/programming_manual/pm0214-stm32-cortexm4-mcus-and-mpus-programming-manual-stmicroelectronics.pdf
Reference Manuals | https://www.st.com/resource/en/reference_manual/rm0440-stm32g4-series-advanced-armbased-32bit-mcus-stmicroelectronics.pdf
Technical Notes & Articles | https://www.st.com/resource/en/technical_note/tn1163-description-of-wlcsp-for-microcontrollers-and-recommendations-for-its-use-stmicroelectronics.pdf
Technical Notes & Articles | https://www.st.com/resource/en/technical_note/tn1204-tape-and-reel-shipping-media-for-stm32-microcontrollers-in-bga-packages-stmicroelectronics.pdf
Technical Notes & Articles | https://www.st.com/resource/en/technical_note/tn1205-tape-and-reel-shipping-media-for-stm8-and-stm32-microcontrollers-in-fpn-packages-stmicroelectronics.pdf
Technical Notes & Articles | https://www.st.com/resource/en/technical_note/tn1206-tape-and-reel-shipping-media-for-stm8-and-stm32-microcontrollers-in-qfp-packages-stmicroelectronics.pdf
Technical Notes & Articles | https://www.st.com/resource/en/technical_note/tn1207-tape-and-reel-shipping-media-for-stm8-and-stm32-microcontrollers-in-so-packages-stmicroelectronics.pdf
Technical Notes & Articles | https://www.st.com/resource/en/technical_note/tn1208-tape-and-reel-shipping-media-for-stm8-and-stm32-microcontrollers-in-tssop-and-ssop-packages-stmicroelectronics.p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
Technical Notes & Articles | https://www.st.com/resource/en/technical_note/tn1433-reference-device-marking-schematics-for-stm32-microcontrollers-and-microprocessors-stmicroelectronics.pdf

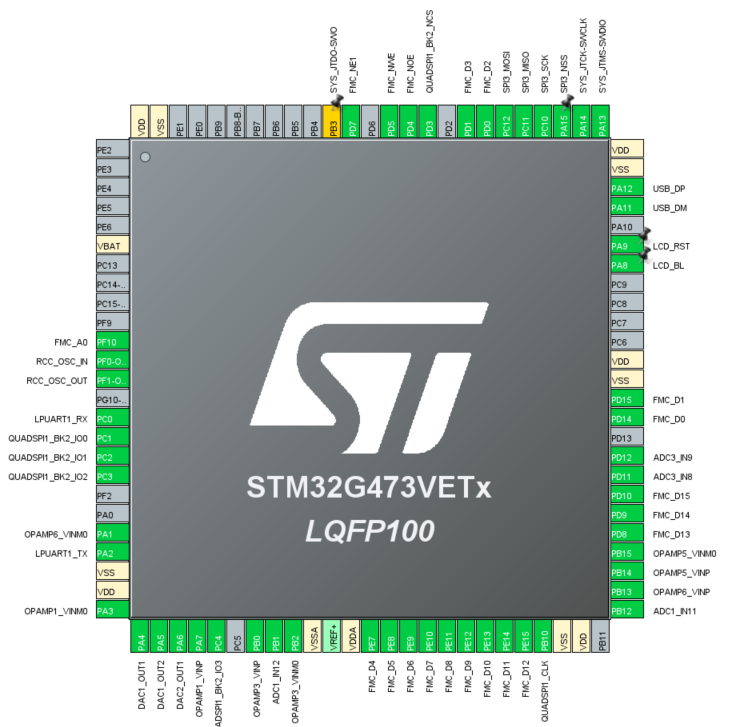
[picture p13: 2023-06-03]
hardware/black_scope/black_scope_pinout.png

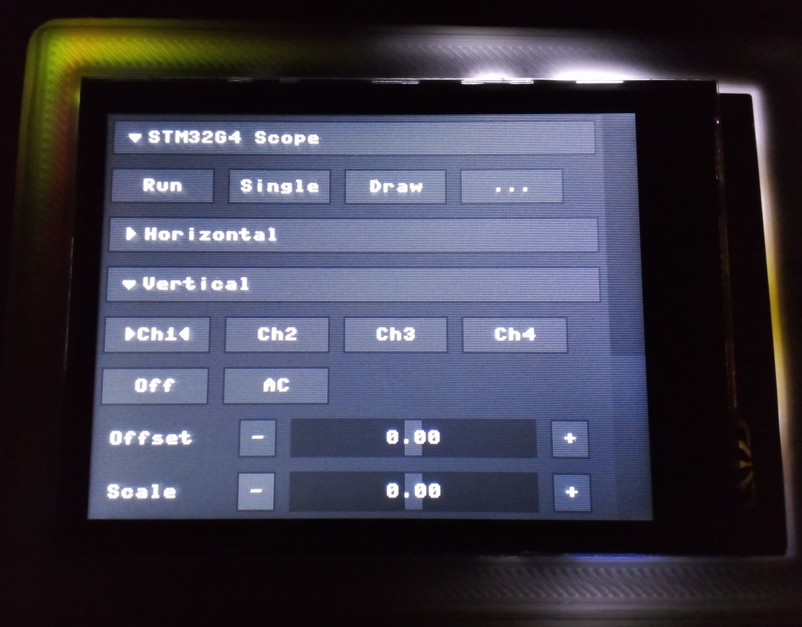
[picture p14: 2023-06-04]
images/scope_gui.jpg

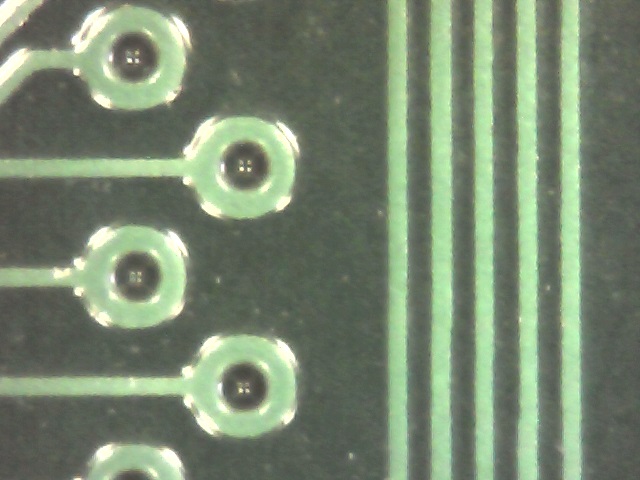
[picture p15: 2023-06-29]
images/pcb detail microscope.jpeg

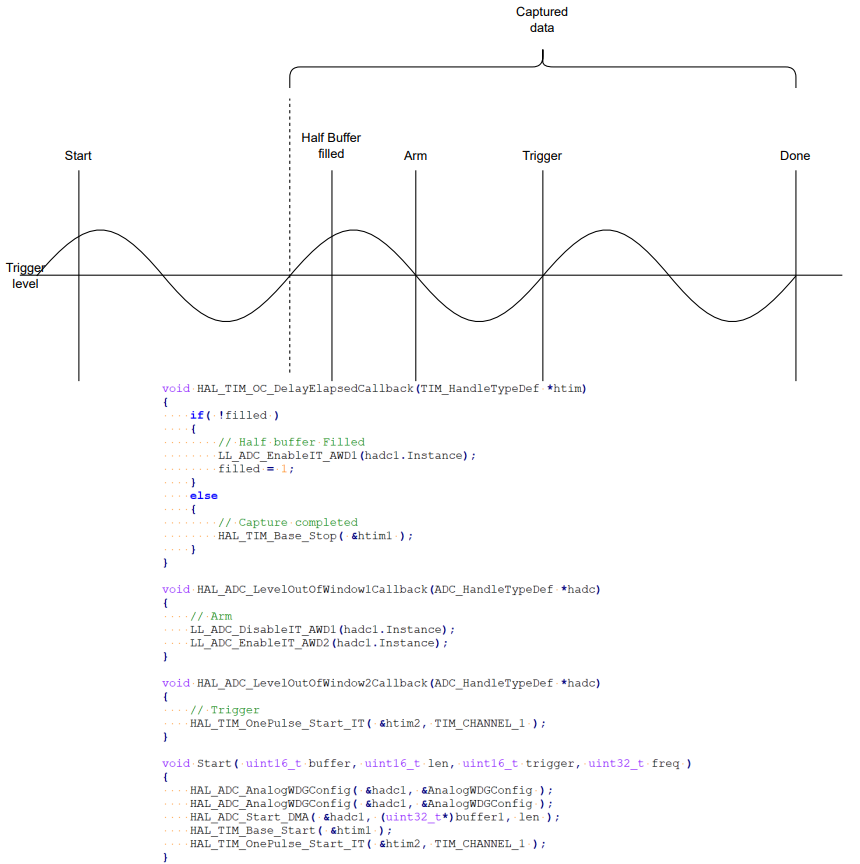
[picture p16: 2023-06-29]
images/capture engine.png

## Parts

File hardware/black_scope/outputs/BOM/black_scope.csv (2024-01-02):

Reference | Value | Footprint | Datasheet | External REF | Mouser REF | Qty
C1, C5, C9-C22, C27-C30 | 100n | Capacitor_SMD:C_0603_1608Metric_Pad1.08x0.95mm_HandSolder | ~ |  |  | 20
C2, C3 | 10p | Capacitor_SMD:C_0603_1608Metric_Pad1.08x0.95mm_HandSolder | ~ |  |  | 2
C4, C6-C8 | 270n | Capacitor_SMD:C_0603_1608Metric_Pad1.08x0.95mm_HandSolder | ~ |  |  | 4
C23-C26 | 100p | Capacitor_SMD:C_0603_1608Metric_Pad1.08x0.95mm_HandSolder | ~ |  |  | 4
D1, D3 | D_Schottky | Diode_SMD:D_1206_3216Metric_Pad1.42x1.75mm_HandSolder | ~ |  | 512-SS24FL | 2
D2 | LED | Diode_SMD:D_0603_1608Metric_Pad1.05x0.95mm_HandSolder | ~ |  |  | 1
D4 | D_Schottky_Dual_CommonCathode_AAK_Parallel | Package_TO_SOT_SMD:SOT-23 | ~ |  | 750-BAT54C-HF | 1
J1 | Conn_ARM_JTAG_SWD_10 | Connector_PinHeader_1.27mm:PinHeader_2x05_P1.27mm_Vertical_SMD | http://infocenter.arm.com/help/topic/com.arm.doc.ddi0314h/DDI0314H_coresight_components_trm.pdf |  | 649-221121-00010T4LF | 1
J2 | Conn_02x06_Odd_Even | Connector_PinHeader_2.54mm:PinHeader_2x06_P2.54mm_Vertical_SMD | ~ |  | 200-TSM10302LDH | 1
J3 | Conn_01x02 | Connector_JST:JST_PH_B2B-PH-K_1x02_P2.00mm_Vertical | ~ |  |  | 1
J4 | Conn_02x04_Odd_Even | Connector_PinHeader_2.54mm:PinHeader_2x04_P2.54mm_Horizontal | ~ |  |  | 1
J5 | Conn_02x02_Odd_Even | Connector_PinHeader_2.54mm:PinHeader_2x02_P2.54mm_Horizontal | ~ |  |  | 1
L1, L2 | 47u | Inductor_SMD:L_0603_1608Metric_Pad1.05x0.95mm_HandSolder | ~ |  | 80-L0603B470KPWFT | 2
P1 | USB_C_Plug_USB2.0 | Connector_USB:USB_C_Receptacle_HRO_TYPE-C-31-M-12 | https://www.usb.org/sites/default/files/documents/usb_type-c.zip |  | 640-USB4105-GF-A | 1
Q3 | Q_NPN_BEC | Package_TO_SOT_SMD:SOT-23 | https://www.mouser.es/datasheet/2/80/SS8050_G_RevA181526-2506539.pdf |  | 750-SS8050-G | 1
R1, R19 | 22 | Resistor_SMD:R_0603_1608Metric_Pad0.98x0.95mm_HandSolder | ~ |  |  | 2
R2, R23-R26 | 10k | Resistor_SMD:R_0603_1608Metric_Pad0.98x0.95mm_HandSolder | ~ |  |  | 5
R3 | 6.8k | Resistor_SMD:R_0603_1608Metric_Pad0.98x0.95mm_HandSolder | ~ |  |  | 1
R4, R22 | 1k | Resistor_SMD:R_0603_1608Metric_Pad0.98x0.95mm_HandSolder | ~ |  |  | 2
R5-R8 | 8k2 | Resistor_SMD:R_0603_1608Metric_Pad0.98x0.95mm_HandSolder | ~ |  | 667-ERJ-3RBD8201V | 4
R9, R10 | 51 | Resistor_SMD:R_0603_1608Metric_Pad0.98x0.95mm_HandSolder | ~ |  |  | 2
R11, R13, R15, R17 | 2k7 | Resistor_SMD:R_0603_1608Metric_Pad0.98x0.95mm_HandSolder | ~ |  | 667-ERJ-3RBD2701V | 4
R12, R14, R16, R18 | 4k3 | Resistor_SMD:R_0603_1608Metric_Pad0.98x0.95mm_HandSolder | ~ |  | 667-ERJ-3RBD4301V | 4
R20, R21 | 27 | Resistor_SMD:R_0603_1608Metric_Pad0.98x0.95mm_HandSolder | ~ |  |  | 2
SW1, SW2 | SW_Push | Button_Switch_SMD:SW_Push_SPST_NO_Alps_SKRK | ~ |  | 688-SKRKAHE010 | 2
TP1-TP4 | TestPoint | TestPoint:TestPoint_Pad_D1.0mm | ~ |  |  | 4
U1 | MCP73831-2-OT | Package_TO_SOT_SMD:SOT-23-5 | http://ww1.microchip.com/downloads/en/DeviceDoc/20001984g.pdf |  | 579-MCP73831T-2DCIOT | 1
U2 | XC6206PxxxMR | Package_TO_SOT_SMD:SOT-23-3 | https://www.torexsemi.com/file/xc6206/XC6206.pdf |  | 579-MCP1700T3302E/TT | 1
U3 | STM32G473VE | Package_QFP:LQFP-100_14x14mm_P0.5mm |  |  | 511-STM32G473VET6 | 1
U4 | LMV358 | Package_SO:TSSOP-8_4.4x3mm_P0.65mm | http://www.ti.com/lit/ds/symlink/lmv324.pdf |  | 595-LMV358IDR | 1
U5 | XPT2046TS | Package_SO:TSSOP-16_4.4x5mm_P0.65mm | http://www.xptek.cn/uploadfile/download/201707171401161883.pdf |  | 595-TSC2046EIPWR | 1
U6 | TFT035IPS | Connector_FFC-FPC:Hirose_FH12-50S-0.5SH_1x50-1MP_P0.50mm_Horizontal |  |  | 649-62684-50210E9ALF | 1
U7 | QSPI_PSRAM | Package_SO:SOIC-8_3.9x4.9mm_P1.27mm |  |  | 878-APS6404L-3SQR-SN | 1
U8 | LMV324 | Package_SO:TSSOP-14_4.4x5mm_P0.65mm | http://www.ti.com/lit/ds/symlink/lmv324.pdf |  | 595-OPA4322AIPWR | 1
Y1 | Crystal_GND24 | Crystal:Crystal_SMD_3225-4Pin_3.2x2.5mm | ~ |  | 732-322524F20GAC0 | 1

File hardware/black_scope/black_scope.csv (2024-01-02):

Source: | C:\git\black_scope\hardware\black_scope\black_scope.kicad_sch
Date: | 8/17/2023 9:18:08 PM
Tool: | Eeschema 7.0.6
Generator: | C:\Program Files\KiCad\7.0\bin\scripting\plugins/bom_csv_grouped_by_value_with_fp.py
Component Count: | 84
Ref | Qnty | Value | Cmp name | Footprint | Description | Vendor | DNP
C1, C5, C9, C10, C11, C12, C13, C14, C15, C16, C17, C18, C19, C20, C21, C22, C27, C28, C29, C30 | 20 | 100n | C | Capacitor_SMD:C_0603_1608Metric_Pad1.08x0.95mm_HandSolder | Unpolarized capacitor
C2, C3 | 2 | 10p | C | Capacitor_SMD:C_0603_1608Metric_Pad1.08x0.95mm_HandSolder | Unpolarized capacitor
C4, C6, C7, C8 | 4 | 270n | C | Capacitor_SMD:C_0603_1608Metric_Pad1.08x0.95mm_HandSolder | Unpolarized capacitor
C23, C24, C25, C26 | 4 | 100p | C | Capacitor_SMD:C_0603_1608Metric_Pad1.08x0.95mm_HandSolder | Unpolarized capacitor
D1, D3 | 2 | D_Schottky | D_Schottky | Diode_SMD:D_1206_3216Metric_Pad1.42x1.75mm_HandSolder | Schottky diode
D2 | 1 | LED | LED | Diode_SMD:D_0603_1608Metric_Pad1.05x0.95mm_HandSolder | Light emitting diode
D4 | 1 | D_Schottky_Dual_CommonCathode_AAK_Parallel | D_Schottky_Dual_CommonCathode_AAK_Parallel | Package_TO_SOT_SMD:SOT-23 | Dual Schottky diode, common anode on pin 1
J1 | 1 | Conn_ARM_JTAG_SWD_10 | Conn_ARM_JTAG_SWD_10 | Connector_PinHeader_1.27mm:PinHeader_2x05_P1.27mm_Vertical_SMD | Cortex Debug Connector, standard ARM Cortex-M SWD and JTAG interface
J2 | 1 | Conn_02x06_Odd_Even | Conn_02x06_Odd_Even | Connector_PinHeader_2.54mm:PinHeader_2x06_P2.54mm_Vertical_SMD | Generic connector, double row, 02x06, odd/even pin numbering scheme (row 1 odd numbers, row 2 even numbers), script generated (kicad-library-utils/schlib/autogen/connector/)
J3 | 1 | Conn_01x02 | Conn_01x02 | Connector_JST:JST_PH_B2B-PH-K_1x02_P2.00mm_Vertical | Generic connector, single row, 01x02, script generated (kicad-library-utils/schlib/autogen/connector/)
J4 | 1 | Conn_02x04_Odd_Even | Conn_02x04_Odd_Even | Connector_PinHeader_2.54mm:PinHeader_2x04_P2.54mm_Horizontal | Generic connector, double row, 02x04, odd/even pin numbering scheme (row 1 odd numbers, row 2 even numbers), script generated (kicad-library-utils/schlib/autogen/connector/)
J5 | 1 | Conn_02x02_Odd_Even | Conn_02x02_Odd_Even | Connector_PinHeader_2.54mm:PinHeader_2x02_P2.54mm_Horizontal | Generic connector, double row, 02x02, odd/even pin numbering scheme (row 1 odd numbers, row 2 even numbers), script generated (kicad-library-utils/schlib/autogen/connector/)
L1, L2 | 2 | 47u | L | Inductor_SMD:L_0603_1608Metric_Pad1.05x0.95mm_HandSolder | Inductor
P1 | 1 | USB_C_Plug_USB2.0 | USB_C_Plug_USB2.0 | Connector_USB:USB_C_Receptacle_HRO_TYPE-C-31-M-12 | USB 2.0-only Type-C Plug connector
Q3 | 1 | Q_NPN_BEC | Q_NPN_BEC | Package_TO_SOT_SMD:SOT-23 | NPN transistor, base/emitter/collector
R1, R19 | 2 | 22 | R | Resistor_SMD:R_0603_1608Metric_Pad0.98x0.95mm_HandSolder | Resistor
R2, R23, R24, R25, R26 | 5 | 10k | R | Resistor_SMD:R_0603_1608Metric_Pad0.98x0.95mm_HandSolder | Resistor
R3 | 1 | 6.8k | R | Resistor_SMD:R_0603_1608Metric_Pad0.98x0.95mm_HandSolder | Resistor
R4, R22 | 2 | 1k | R | Resistor_SMD:R_0603_1608Metric_Pad0.98x0.95mm_HandSolder | Resistor
R5, R6, R7, R8 | 4 | 8k2 | R | Resistor_SMD:R_0603_1608Metric_Pad0.98x0.95mm_HandSolder | Resistor
R9, R10 | 2 | 51 | R | Resistor_SMD:R_0603_1608Metric_Pad0.98x0.95mm_HandSolder | Resistor
R11, R13, R15, R17 | 4 | 2k7 | R | Resistor_SMD:R_0603_1608Metric_Pad0.98x0.95mm_HandSolder | Resistor
R12, R14, R16, R18 | 4 | 4k3 | R | Resistor_SMD:R_0603_1608Metric_Pad0.98x0.95mm_HandSolder | Resistor
R20, R21 | 2 | 27 | R | Resistor_SMD:R_0603_1608Metric_Pad0.98x0.95mm_HandSolder | Resistor
SW1, SW2 | 2 | SW_Push | SW_Push | Button_Switch_SMD:SW_Push_SPST_NO_Alps_SKRK | Push button switch, generic, two pins
TP1, TP2, TP3, TP4 | 4 | TestPoint | TestPoint | TestPoint:TestPoint_Pad_D1.0mm | test point
U1 | 1 | MCP73831-2-OT | MCP73831-2-OT | Package_TO_SOT_SMD:SOT-23-5 | Single cell, Li-Ion/Li-Po charge management controller, 4.20V, Tri-State Status Output, in SOT23-5 package
U2 | 1 | XC6206PxxxMR | XC6206PxxxMR | Package_TO_SOT_SMD:SOT-23-3 | Positive 60-250mA Low Dropout Regulator, Fixed Output, SOT-23
U3 | 1 | STM32G473VE | STM32G473VE | Package_QFP:LQFP-100_14x14mm_P0.5mm
U4 | 1 | LMV358 | LMV358 | Package_SO:TSSOP-8_4.4x3mm_P0.65mm | Dual Low-Voltage Rail-to-Rail Output Operational Amplifiers, SOIC-8/SSOP-8
U5 | 1 | XPT2046TS | XPT2046TS | Package_SO:TSSOP-16_4.4x5mm_P0.65mm | Single-supply, 12bit, 4 ch, touch screen driver, 2.2 - 5.25 VDD, -40 to +85 C, QSPI, SPI, 3-wire serial interface, TSSOP-16
U6 | 1 | TFT035IPS | TFT035IPS | Connector_FFC-FPC:Hirose_FH12-50S-0.5SH_1x50-1MP_P0.50mm_Horizontal
U7 | 1 | QSPI_PSRAM | QSPI_PSRAM | Package_SO:SOIC-8_3.9x4.9mm_P1.27mm
U8 | 1 | LMV324 | LMV324 | Package_SO:TSSOP-14_4.4x5mm_P0.65mm | Quad Low-Voltage Rail-to-Rail Output Operational Amplifier, SOIC-14/SSOP-14
Y1 | 1 | Crystal_GND24 | Crystal_GND24 | Crystal:Crystal_SMD_3225-4Pin_3.2x2.5mm | Four pin crystal, GND on pins 2 and 4

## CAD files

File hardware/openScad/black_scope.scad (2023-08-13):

//-----------------------------------------------------------------------
// Yet Another Parameterized Projectbox generator
//
//  This is a box for <template>
//
//  Version 1.6 (06-10-2022)
//
// This design is parameterized based on the size of a PCB.
//
//  for many or complex cutoutGrills you might need to adjust
//  the number of elements:
//
//      Preferences->Advanced->Turn of rendering at 100000 elements
//                                                  ^^^^^^
//
//-----------------------------------------------------------------------

// Subir 0.66mm para el conector JTAG
// Ampliar el conector para el USB
translate([-100+4.4+2,-71+0.3+2,4.6-0.4+1+1+5.87+1.5-2-0.5-5.35])
{
    scale(10*2.54)
    {
        rotate([0,180,180])
        {
            //import( "C:/git/black_scope/black_scope/hardware/black_scope/black_scope.stl" );
        }
    }
}

translate([46.9+1,35.0-1,11.1-5.35])
{
    rotate([0,0,90])
    {
        scale(10*2.54){
          // # import( "C:/Users/Jose/Downloads/ER-TFT035-6.stl" );
        }
    }
}

polygonShape = [  [0,0],[20,15],[30,0],[40,15],[70,15]
                 ,[50,30],[60,45], [40,45],[30,70]
                 ,[20,45], [0,45]
               ];


include <../../../YAPP_Box/library/YAPPgenerator_v16.scad>

// Note: length/lengte refers to X axis, 
//       width/breedte to Y, 
//       height/hoogte to Z

/*
            padding-back>|<---- pcb length ---->|<padding-front
                                 RIGHT
                   0    X-ax ---> 
               +----------------------------------------+   ---
               |                                        |    ^
               |                                        |   padding-right 
             ^ |                                        |    v
             | |    -5,y +----------------------+       |   ---              
        B    Y |         | 0,y              x,y |       |     ^              F
        A    - |         |                      |       |     |              R
        C    a |         |                      |       |     | pcb width    O
        K    x |         |                      |       |     |              N
               |         | 0,0              x,0 |       |     v              T
               |   -5,0  +----------------------+       |   ---
               |                                        |    padding-left
             0 +----------------------------------------+   ---
               0    X-ax --->
                                 LEFT
*/

printBaseShell      = true;
printLidShell       = true;

// Edit these parameters for your own board dimensions
wallThickness       = 4.0;
basePlaneThickness  = 2.0;
lidPlaneThickness   = 1.0;

baseWallHeight      = 4;
lidWallHeight       = 3.1;

// ridge where base and lid off box can overlap
// Make sure this isn't less than lidWallHeight
ridgeHeight         = 3;
ridgeSlack          = 0.2;
roundRadius         = 4.0;

// How much the PCB needs to be raised from the base
// to leave room for solderings and whatnot
standoffHeight      = 2;
pinDiameter         = 0;
pinHoleSlack        = 0;
standoffDiameter    = 4;

// Total height of box = basePlaneThickness + lidPlaneThickness 
//                     + baseWallHeight + lidWallHeight
pcbLength           = 89;//87;
pcbWidth            = 60.5-0.4;//59;
pcbThickness        = 1.7;
                            
// padding between pcb and inside wall
paddingFront        = 0.4;
paddingBack         = 0.4;
paddingRight        = 0.4;
paddingLeft         = 0.4;


//-- D E B U G -------------------
showSideBySide      = true;
//showSideBySide      = false;
hideLidWalls        = false;
onLidGap            = 0;
shiftLid            = -8;
colorLid            = "yellow";
hideBaseWalls       = false;
colorBase           = "white";
showPCB             = false;
//showPCB             = true;
showMarkers         = false;
inspectX            = 0;  // 0=none, >0 from front, <0 from back
inspectY            = 0;  // 0=none, >0 from left, <0 from right


//-- pcb_standoffs  -- origin is pcb[0,0,0]
// (0) = posx
// (1) = posy
// (2) = { yappBoth | yappLidOnly | yappBaseOnly }
// (3) = { yappHole, YappPin }
_pcbStands = [
                [35,  6, yappBaseOnly, yappHole],
           //     [72,  7, yappBaseOnly, yappHole], 
           //     [72,  52, yappBaseOnly, yappHole],
               [16,  25, yappBaseOnly, yappHole],
              [16,  45, yappBaseOnly, yappHole], 
              
              [63,  4, yappBaseOnly, yappHole], 
              [83,  4, yappBaseOnly, yappHole],
              [83,  59-4, yappBaseOnly, yappHole],
              [51,  11, yappBaseOnly, yappHole], 
              [51,  46, yappBaseOnly, yappHole], 
              

              [0,  0, yappBaseOnly, yappHole], 
              [0,  pcbWidth, yappBaseOnly, yappHole],
             [pcbLength,  0, yappBaseOnly, yappHole],
            [ pcbLength, pcbWidth, yappBaseOnly, yappHole],
            
             ];     

//-- Lid plane    -- origin is pcb[0,0,0]
// (0) = posx
// (1) = posy
// (2) = width
// (3) = length
// (4) = angle
// (5) = { yappRectangle | yappCircle }
// (6) = { yappCenter }
cutoutsLid =  [
                    //[2, 2, 55, 83, 0, yappRectangle]  
                    [2+1.22+1, 2+1.8+0.75, 48.96+2, 73.44+2, 0, yappRectangle]  
               //   , [20, 50, 10, 20, 0, yappRectangle, yappCenter]
               //   , [50, 50, 10, 2, 0, yappCircle]
               //   , [pcbLength-10, 20, 15, 0, 0, yappCircle] 
               //   , [50, pcbWidth, 5, 7, 0, yappRectangle, yappCenter]
              ];

//-- base plane    -- origin is pcb[0,0,0]
// (0) = posx
// (1) = posy
// (2) = width
// (3) = length
// (4) = angle
// (5) = { yappRectangle | yappCircle }
// (6) = { yappCenter }
cutoutsBase =   [
                    [-3, 1.8-0.2+0.75, 16+0.4, 11.5, 0, yappRectangle],
                    //[2, 50.8, 6.4, 4.9, 0, yappRectangle],
                    //[-3, 24.7, 9.9, 10.3, 0, yappRectangle],
                    [39, 4+0.75, 2, 8, 0, yappRectangle],
                    [24.765, 42.235+0.75, 3.53, 6.47, 0, yappRectangle],
                    [22.5-0.2, 42.000+0.75, 4, 11+0.4, 0, yappRectangle],
                    [22.5+4, 42.000+0.75, 5, 3, 0, yappRectangle],
                    [5.36, 40+0.75, 2, 0, 0, yappCircle],
                    [5.36, 44+0.75, 2, 0, 0, yappCircle],
                    //[14, 51+0.75, 1.5, 0, 0, yappCircle],
                    [3, 54.75, 1.5, 0, 0, yappCircle],
                    
                    [-5.5, 24.7+0.75-(12.7-9.9)/2, 12.7, 3.5, 0, yappRectangle],
                    [-5.5, 24.7+0.75, 9.9, 9.9+3, 0, yappRectangle],
                 // , [30, 10, 15, 10, 45, yappRectangle, yappCenter]
                 // , [20, pcbWidth-20, 15, 0, 0, yappCircle]
                 // , [pcbLength-15, 5, 10, 2, 0, yappCircle]
                ];

//-- front plane  -- origin is pcb[0,0,0]
// (0) = posy
// (1) = posz
// (2) = width
// (3) = height
// (4) = angle
// (5) = { yappRectangle | yappCircle }
// (6) = { yappCenter }
cutoutsFront =  [
               //     [0, 5, 10, 15, 0, yappRectangle]               // org
               //  ,  [25, 3, 10, 10, 0, yappRectangle, yappCenter]  // center
               //  ,  [60, 10, 15, 6, 0, yappCircle]                 // circle
                ];

//-- back plane  -- origin is pcb[0,0,0]
// (0) = posy
// (1) = posz
// (2) = width
// (3) = height
// (4) = angle
// (5) = { yappRectangle | yappCircle }
// (6) = { yappCenter }
cutoutsBack =   [
                [1.8-0.2+0.75, -5.5, 16+0.4, 3.4, 0, yappRectangle],
                [24.7+0.75+1.4-(12.7-9.9), -5.5+2.5, 12.7, 3.4, 0, yappRectangle],
                //[ 24.7+0.75-(12.7-9.9)/2, -1.6-3.5, 12.7, 3.5, 0, yappRectangle],
                //  , [25, 18, 10, 6, 0, yappRectangle, yappCenter]  // center
                //  , [50, 0, 8, 8, 0, yappCircle]                   // circle
                ];

//-- left plane   -- origin is pcb[0,0,0]
// (0) = posx
// (1) = posz
// (2) = width
// (3) = height
// (4) = angle
// (5) = { yappRectangle | yappCircle }
// (6) = { yappCenter }
cutoutsLeft =   [
                 //   [25, 0, 6, 20, 0, yappRectangle]                       // org
                 // , [pcbLength-35, 0, 20, 6, 0, yappRectangle, yappCenter] // center
                 // , [pcbLength/2, 10, 20, 6, 0, yappCircle]                // circle
                ];

//-- right plane   -- origin is pcb[0,0,0]
// (0) = posx
// (1) = posz
// (2) = width
// (3) = height
// (4) = angle
// (5) = { yappRectangle | yappCircle }
// (6) = { yappCenter }
cutoutsRight =  [
                 //   [10, 0, 9, 5, 0, yappRectangle]                // org
                 // , [40, 0, 9, 5, 0, yappRectangle, yappCenter]    // center
                 // , [60, 0, 9, 5, 0, yappCircle]                   // circle
                ];
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

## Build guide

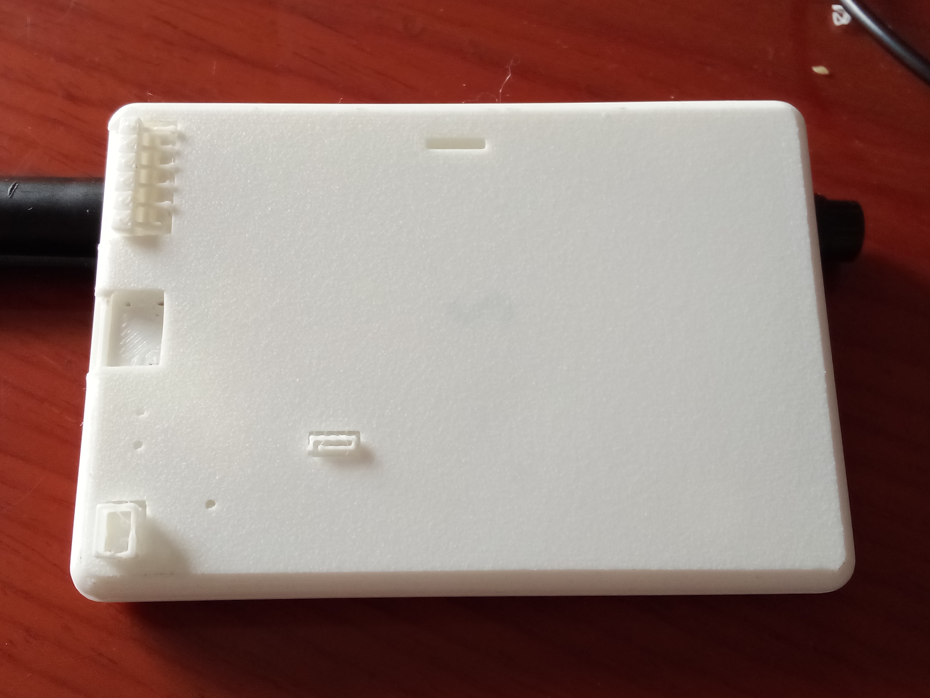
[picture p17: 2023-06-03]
images/case_back_3d_print.jpg

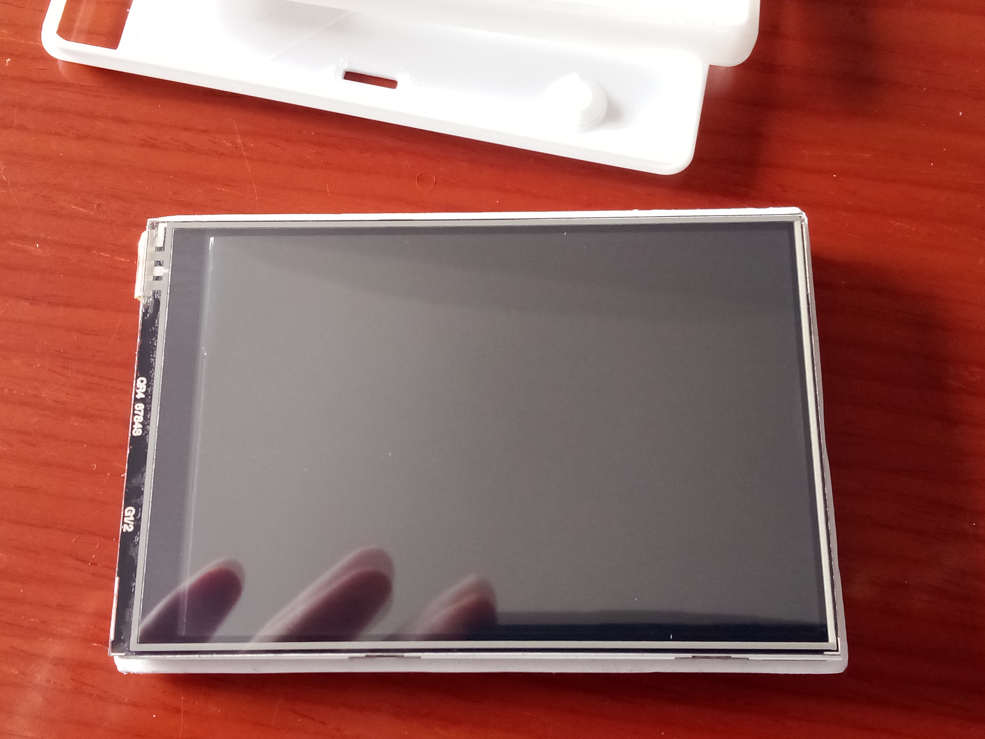
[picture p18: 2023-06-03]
images/tft_front_3d_print.jpg

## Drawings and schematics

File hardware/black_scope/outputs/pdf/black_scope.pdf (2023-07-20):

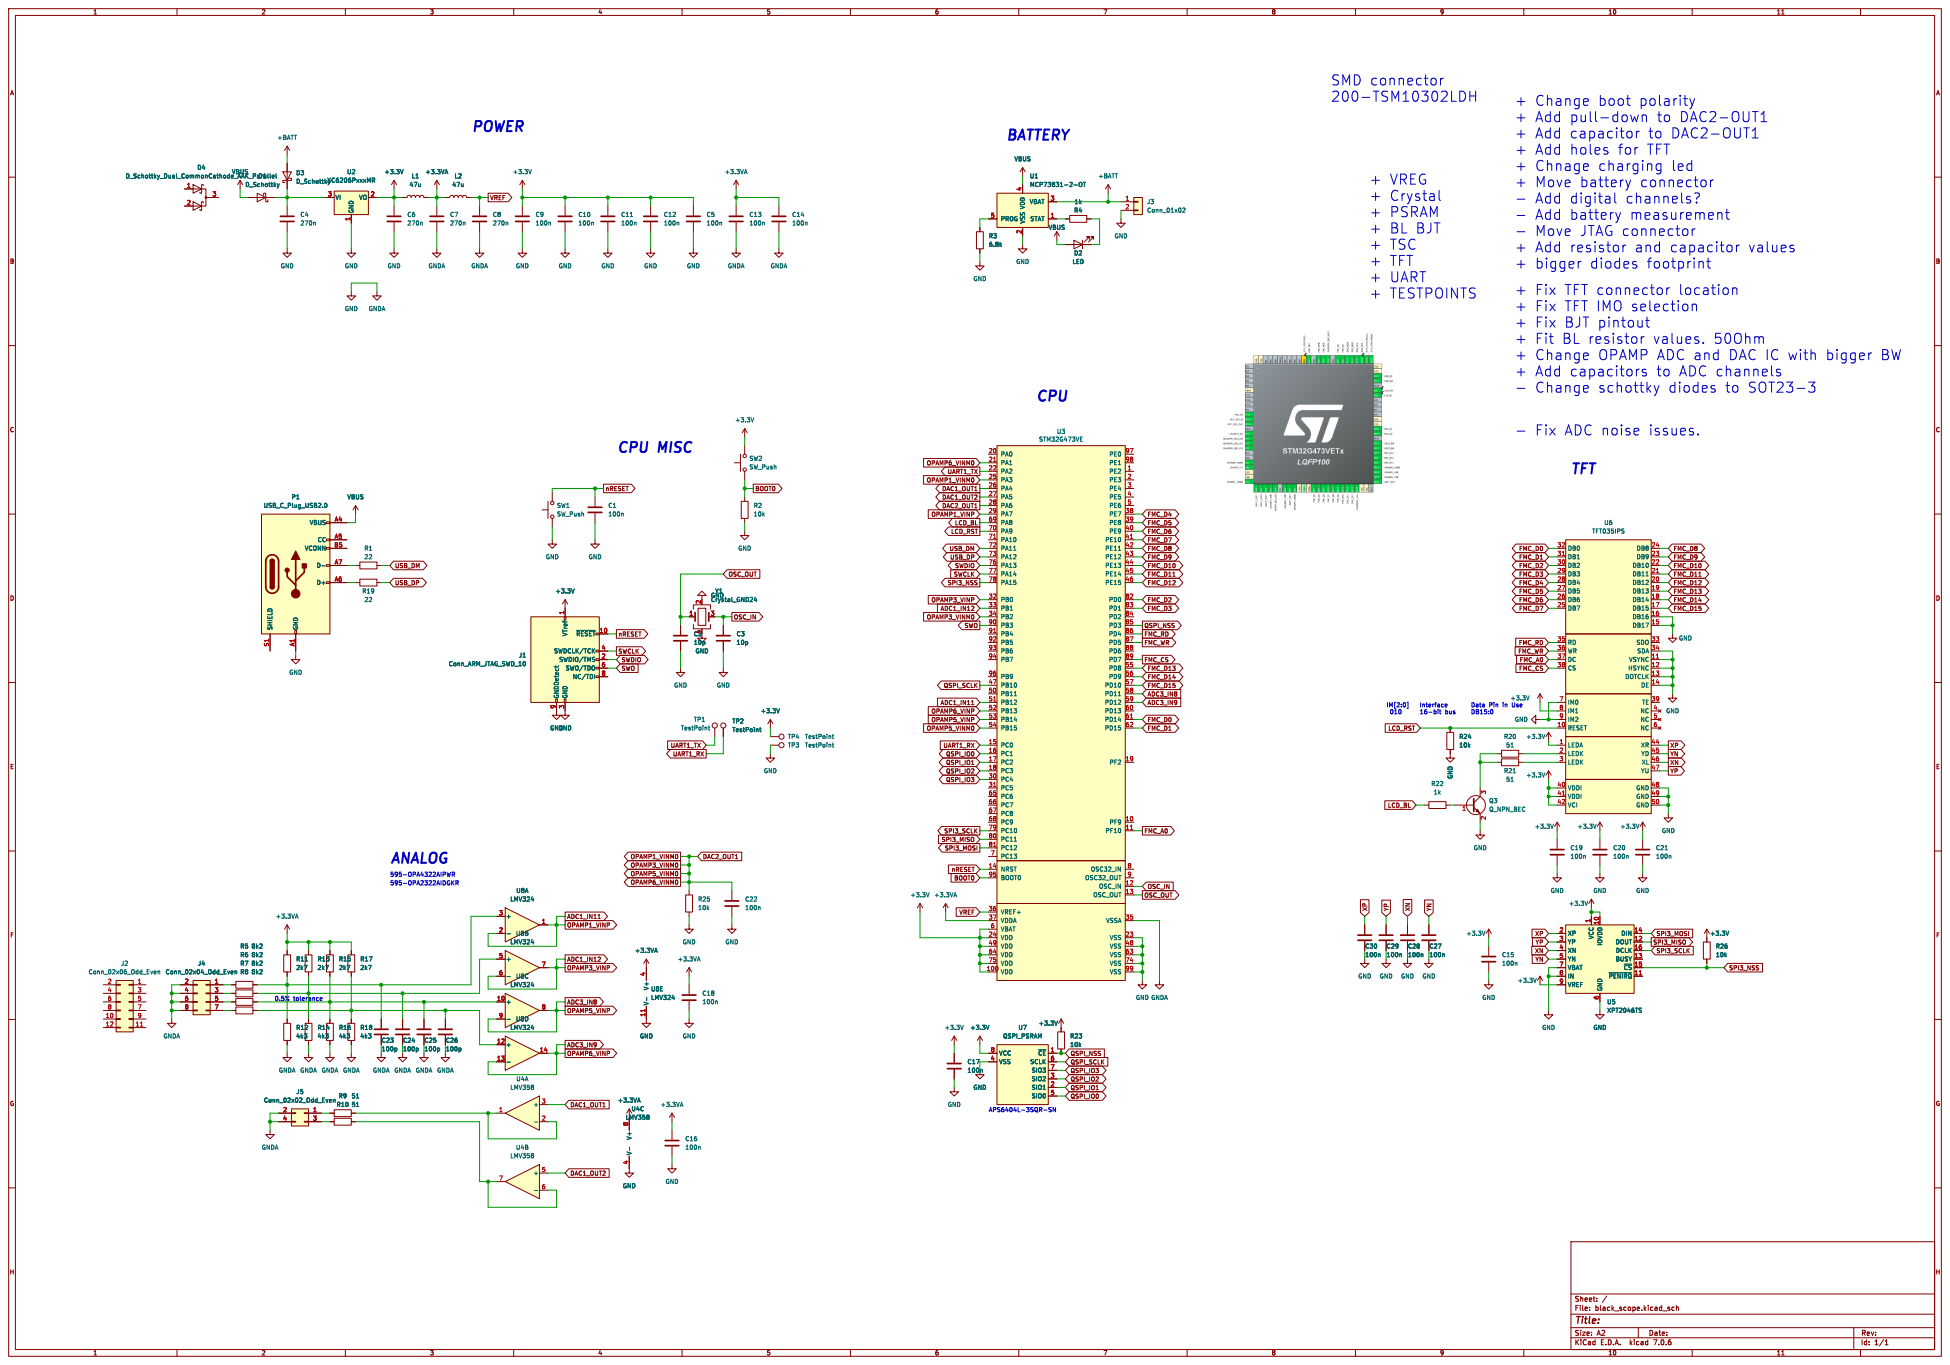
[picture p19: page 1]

+ Change boot polarity
+ Add holes for TFT
+ Chnage charging led
+ Move battery connector
- Add digital channels?
- Add battery measurement - Move JTAG connector

+ Fix TFT IMO selection
+ Fix BJT pintout
+ Fit BL resistor values. 50Ohm
+ Change OPAMP ADC and DAC IC with bigger BW
- Change schottky diodes to SOT23-3

3 SWDCLK/TCK 4 SWO/TDO 6 NC/TDI 8 GNDDetect 9 P1 VBUS USB_C_Plug_USB2.0 GND A1 VBUS A4 CC A5 D+ A6 D- A7 VCONN B5 SHIELD S1

3 SWDCLK/TCK 4 SWO/TDO 6 NC/TDI 8 GNDDetect 9

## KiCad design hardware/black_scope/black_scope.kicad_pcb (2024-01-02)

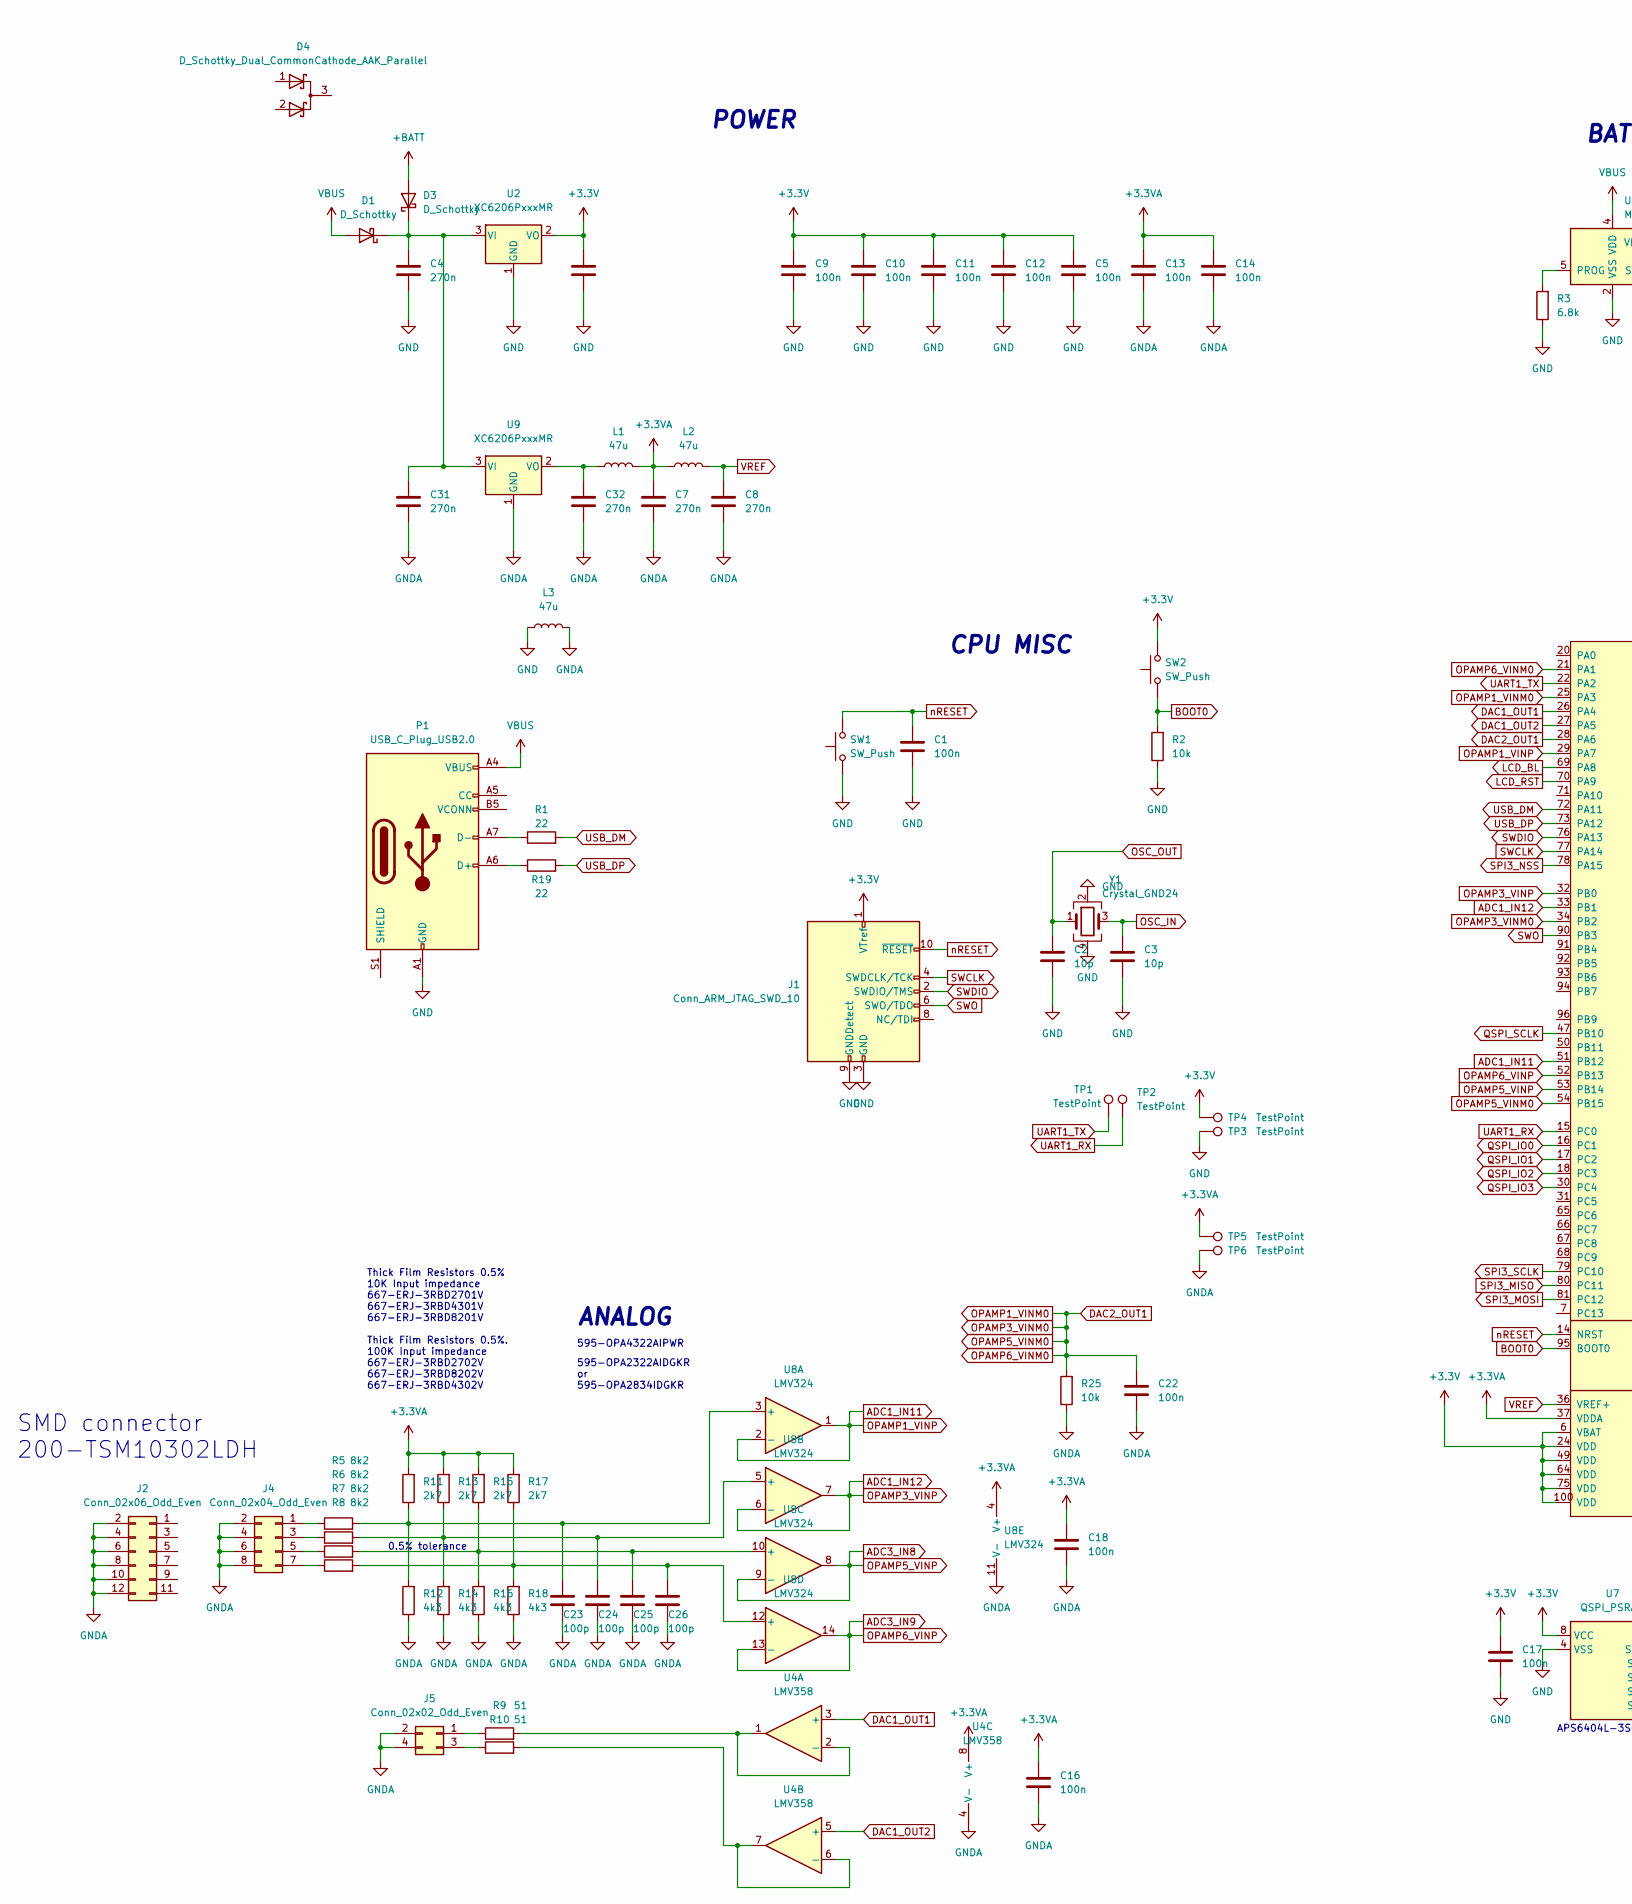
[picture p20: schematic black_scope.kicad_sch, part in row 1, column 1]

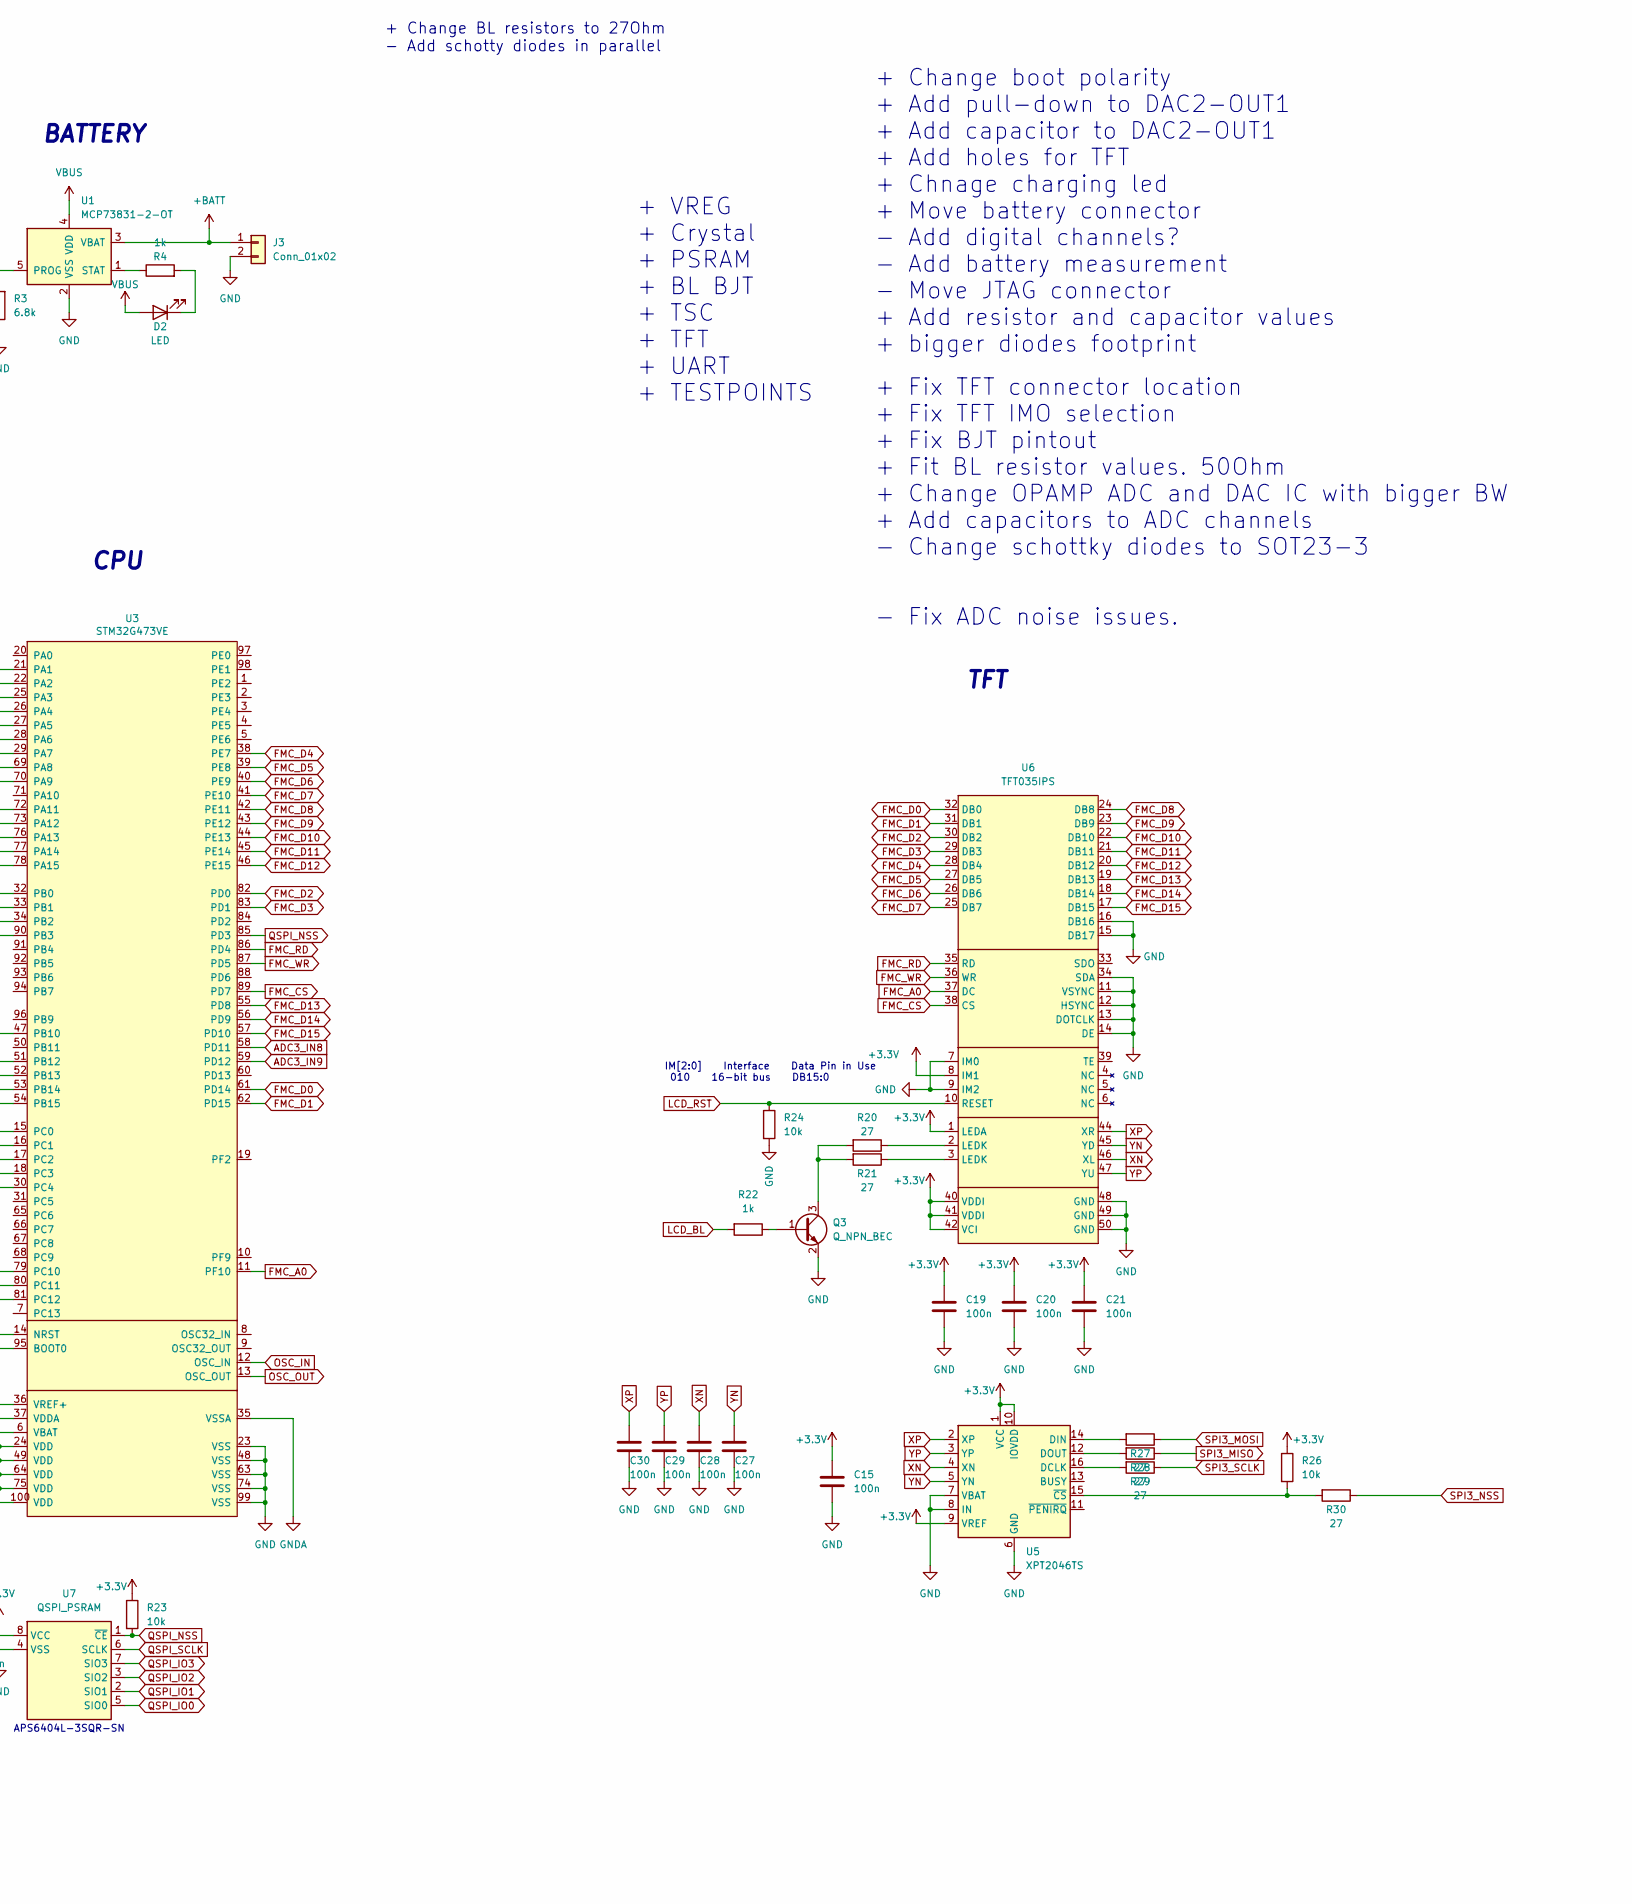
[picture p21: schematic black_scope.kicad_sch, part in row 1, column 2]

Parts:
C1, C5, C9, C10, C11, C12, C13, C14, C15, C16, C17, C18, C19, C20, C21, C22, C27, C28, C29, C30: 100n; C_0603_1608Metric_Pad1.08x0.95mm_HandSolder
C2, C3: 10p; C_0603_1608Metric_Pad1.08x0.95mm_HandSolder
C4, C6, C7, C8, C31, C32: 270n; C_0603_1608Metric_Pad1.08x0.95mm_HandSolder
C23, C24, C25, C26: 100p; C_0603_1608Metric_Pad1.08x0.95mm_HandSolder
D1, D3: D_Schottky; D_1206_3216Metric_Pad1.42x1.75mm_HandSolder; Mouser REF 512-SS24FL
D2: LED; D_0603_1608Metric_Pad1.05x0.95mm_HandSolder
D4: D_Schottky_Dual_CommonCathode_AAK_Parallel; SOT-23; Mouser REF 750-BAT54C-HF
J1: Conn_ARM_JTAG_SWD_10; PinHeader_2x05_P1.27mm_Vertical_SMD; Mouser REF 649-221121-00010T4LF
J2: Conn_02x06_Odd_Even; PinHeader_2x06_P2.54mm_Vertical_SMD; Mouser REF 200-TSM10302LDH
J3: Conn_01x02; JST_PH_B2B-PH-K_1x02_P2.00mm_Vertical
J4: Conn_02x04_Odd_Even; PinHeader_2x04_P2.54mm_Horizontal
J5: Conn_02x02_Odd_Even; PinHeader_2x02_P2.54mm_Horizontal
L1, L2, L3: 47u; L_0603_1608Metric_Pad1.05x0.95mm_HandSolder; Mouser REF 80-L0603B470KPWFT
P1: USB_C_Plug_USB2.0; USB_C_Receptacle_HRO_TYPE-C-31-M-12; Mouser REF 640-USB4105-GF-A
Q3: Q_NPN_BEC; SOT-23; Mouser REF 750-SS8050-G
R1, R19: 22; R_0603_1608Metric_Pad0.98x0.95mm_HandSolder
R2, R23, R24, R25, R26: 10k; R_0603_1608Metric_Pad0.98x0.95mm_HandSolder
R3: 6.8k; R_0603_1608Metric_Pad0.98x0.95mm_HandSolder
R4, R22: 1k; R_0603_1608Metric_Pad0.98x0.95mm_HandSolder
R5, R6, R7, R8: 8k2; R_0603_1608Metric_Pad0.98x0.95mm_HandSolder; Mouser REF 667-ERJ-3RBD8201V
R9, R10: 51; R_0603_1608Metric_Pad0.98x0.95mm_HandSolder
R11, R13, R15, R17: 2k7; R_0603_1608Metric_Pad0.98x0.95mm_HandSolder; Mouser REF 667-ERJ-3RBD2701V
R12, R14, R16, R18: 4k3; R_0603_1608Metric_Pad0.98x0.95mm_HandSolder; Mouser REF 667-ERJ-3RBD4301V
R20, R21, R27, R28, R29, R30: 27; R_0603_1608Metric_Pad0.98x0.95mm_HandSolder
SW1, SW2: SW_Push; SW_Push_SPST_NO_Alps_SKRK; Mouser REF 688-SKRKAHE010
TP1, TP2, TP3, TP4, TP5, TP6: TestPoint; TestPoint_Pad_D1.0mm
U1: MCP73831-2-OT; SOT-23-5; Mouser REF 579-MCP73831T-2DCIOT
U2, U9: XC6206PxxxMR; SOT-23-3; Mouser REF 579-MCP1700T3302E/TT
U3: STM32G473VE; LQFP-100_14x14mm_P0.5mm; Mouser REF 511-STM32G473VET6
U4: LMV358; TSSOP-8_4.4x3mm_P0.65mm; Mouser REF 595-LMV358IDR
U5: XPT2046TS; TSSOP-16_4.4x5mm_P0.65mm; Mouser REF 595-TSC2046EIPWR
U6: TFT035IPS; Hirose_FH12-50S-0.5SH_1x50-1MP_P0.50mm_Horizontal; Mouser REF 649-62684-50210E9ALF
U7: QSPI_PSRAM; SOIC-8_3.9x4.9mm_P1.27mm; Mouser REF 878-APS6404L-3SQR-SN
U8: LMV324; TSSOP-14_4.4x5mm_P0.65mm; Mouser REF 595-OPA4322AIPWR
Y1: Crystal_GND24; Crystal_SMD_3225-4Pin_3.2x2.5mm; Mouser REF 732-322524F20GAC0

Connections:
+3.3V: C5.1, C6.1, C9.1, C10.1, C11.1, C12.1, C15.1, C17.1, C19.1, C20.1, C21.1, J1.1 (VTref), R23.1, R26.1, SW2.2, TP4.1, U2.2 (VO), U3.6 (VBAT), U3.24 (VDD), U3.49 (VDD), U3.64 (VDD), U3.75 (VDD), U3.100 (VDD), U5.1 (VCC), U5.9 (VREF), U5.10 (IOVDD), U6.1 (LEDA), U6.8 (IM1), U6.40 (VDDI), U6.41 (VDDI), U6.42 (VCI), U7.8 (VCC)
+3.3VA: C7.1, C13.1, C14.1, C16.1, C18.1, L1.2, L2.1, R11.2, R13.2, R15.2, R17.2, TP5.1, U3.37 (VDDA), U4.8 (V+), U8.4 (V+)
+BATT: D3.2 (A), J3.1, U1.3 (VBAT)
ADC1_IN11: U3.29 (PA7), U3.51 (PB12), U8.1, U8.2 (-)
ADC1_IN12: U3.32 (PB0), U3.33 (PB1), U8.6 (-), U8.7
ADC3_IN8: U3.53 (PB14), U3.58 (PD11), U8.8, U8.9 (-)
ADC3_IN9: U3.52 (PB13), U3.59 (PD12), U8.13 (-), U8.14
BOOT0: R2.2, SW2.1, U3.95 (BOOT0)
DAC1_OUT1: U3.26 (PA4), U4.3 (+)
DAC1_OUT2: U3.27 (PA5), U4.5 (+)
DAC2_OUT1: C22.1, R25.2, U3.21 (PA1), U3.25 (PA3), U3.28 (PA6), U3.34 (PB2), U3.54 (PB15)
FMC_A0: U3.11 (PF10), U6.37 (DC)
FMC_CS: U3.89 (PD7), U6.38 (CS)
FMC_D0: U3.61 (PD14), U6.32 (DB0)
FMC_D1: U3.62 (PD15), U6.31 (DB1)
FMC_D2: U3.82 (PD0), U6.30 (DB2)
FMC_D3: U3.83 (PD1), U6.29 (DB3)
FMC_D4: U3.38 (PE7), U6.28 (DB4)
FMC_D5: U3.39 (PE8), U6.27 (DB5)
FMC_D6: U3.40 (PE9), U6.26 (DB6)
FMC_D7: U3.41 (PE10), U6.25 (DB7)
FMC_D8: U3.42 (PE11), U6.24 (DB8)
FMC_D9: U3.43 (PE12), U6.23 (DB9)
FMC_D10: U3.44 (PE13), U6.22 (DB10)
FMC_D11: U3.45 (PE14), U6.21 (DB11)
FMC_D12: U3.46 (PE15), U6.20 (DB12)
FMC_D13: U3.55 (PD8), U6.19 (DB13)
FMC_D14: U3.56 (PD9), U6.18 (DB14)
FMC_D15: U3.57 (PD10), U6.17 (DB15)
FMC_RD: U3.86 (PD4), U6.35 (RD)
FMC_WR: U3.87 (PD5), U6.36 (WR)
GND: C1.2, C2.2, C3.2, C4.2, C5.2, C6.2, C9.2, C10.2, C11.2, C12.2, C15.2, C17.2, C19.2, C20.2, C21.2, C27.2, C28.2, C29.2, C30.2, J1.3 (GND), J1.5 (GND), J1.9 (GNDDetect), J3.2, L3.1, P1.A1 (GND), P1.A12 (GND), P1.B1 (GND), P1.B12 (GND), Q3.2 (E), R2.1, R3.1, R24.2, SW1.1, TP3.1, U1.2 (VSS), U2.1 (GND), U3.23 (VSS), U3.48 (VSS), U3.63 (VSS), U3.74 (VSS), U3.99 (VSS), U5.6 (GND), U5.7 (VBAT), U5.8 (IN), U6.7 (IM0), U6.9 (IM2), U6.11 (VSYNC), U6.12 (HSYNC), U6.13 (DOTCLK), U6.14 (DE), U6.15 (DB17), U6.16 (DB16), U6.34 (SDA), U6.48 (GND), U6.49 (GND), U6.50 (GND), U7.4 (VSS), Y1.2, Y1.4
GNDA: C7.2, C8.2, C13.2, C14.2, C16.2, C18.2, C22.2, C23.2, C24.2, C25.2, C26.2, C31.2, C32.2, J2.2, J2.4, J2.6, J2.8, J2.10, J2.12, J4.2, J4.4, J4.6, J4.8, J5.2, J5.4, L3.2, R12.1, R14.1, R16.1, R18.1, R25.1, TP6.1, U3.35 (VSSA), U4.4 (V-), U8.11 (V-), U9.1 (GND)
LCD_BL: R22.2, U3.69 (PA8)
LCD_RST: R24.1, U3.70 (PA9), U6.10 (RESET)
unnamed: C4.1, C31.1, D1.1 (K), D3.1 (K), U2.3 (VI), U9.3 (VI)
unnamed: D2.1 (K), R4.2
unnamed: J4.1, R5.1
unnamed: J4.3, R6.1
unnamed: J4.5, R7.1
unnamed: J4.7, R8.1
unnamed: J5.1, R9.1
unnamed: J5.3, R10.1
unnamed: P1.A6 (D+), R19.1
unnamed: P1.A7 (D-), R1.1
unnamed: Q3.1 (B), R22.1
unnamed: Q3.3 (C), R20.2, R21.2
unnamed: R20.1, U6.2 (LEDK)
unnamed: R21.1, U6.3 (LEDK)
unnamed: R3.2, U1.5 (PROG)
unnamed: R4.1, U1.1 (STAT)
unnamed: R9.2, U4.1, U4.2 (-)
unnamed: R10.2, U4.6 (-), U4.7
unnamed: R29.2, U5.16 (DCLK)
unnamed: R27.2, U5.14 (DIN)
unnamed: R28.2, U5.12 (DOUT)
unnamed: R26.2, R30.2, U5.15 (~CS)
unnamed: C23.1, R5.2, R11.1, R12.2, U8.3 (+)
unnamed: C24.1, R6.2, R13.1, R14.2, U8.5 (+)
unnamed: C25.1, R7.2, R15.1, R16.2, U8.10 (+)
unnamed: C26.1, R8.2, R17.1, R18.2, U8.12 (+)
unnamed: C32.1, L1.1, U9.2 (VO)
OSC_IN: C3.1, U3.12 (OSC_IN), Y1.3
OSC_OUT: C2.1, U3.13 (OSC_OUT), Y1.1
QSPI_IO0: U3.16 (PC1), U7.5 (SIO0)
QSPI_IO1: U3.17 (PC2), U7.2 (SIO1)
QSPI_IO2: U3.18 (PC3), U7.3 (SIO2)
QSPI_IO3: U3.30 (PC4), U7.7 (SIO3)
QSPI_NSS: R23.2, U3.85 (PD3), U7.1 (~CE)
QSPI_SCLK: U3.47 (PB10), U7.6 (SCLK)
SPI3_MISO: R28.1, U3.80 (PC11)
SPI3_MOSI: R27.1, U3.81 (PC12)
SPI3_NSS: R30.1, U3.78 (PA15)
SPI3_SCLK: R29.1, U3.79 (PC10)
SWCLK: J1.4 (SWDCLK/TCK), U3.77 (PA14)
SWDIO: J1.2 (SWDIO/TMS), U3.76 (PA13)
SWO: J1.6 (SWO/TDO), U3.90 (PB3)
UART1_RX: TP2.1, U3.15 (PC0)
UART1_TX: TP1.1, U3.22 (PA2)
USB_DM: R1.2, U3.72 (PA11)
USB_DP: R19.2, U3.73 (PA12)
VBUS: D1.2 (A), D2.2 (A), P1.A4 (VBUS), P1.A9 (VBUS), P1.B4 (VBUS), P1.B9 (VBUS), U1.4 (VDD)
VREF: C8.1, L2.2, U3.36 (VREF+)
XN: C28.1, U5.4 (XN), U6.46 (XL)
XP: C30.1, U5.2 (XP), U6.44 (XR)
YN: C27.1, U5.5 (YN), U6.45 (YD)
YP: C29.1, U5.3 (YP), U6.47 (YU)
nRESET: C1.1, J1.10 (~RESET), SW1.2, U3.14 (NRST)

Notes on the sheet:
+ Change boot polarity + Add pull-down to DAC2-OUT1 + Add capacitor to DAC2-OUT1 + Add holes for TFT + Chnage charging led + Move battery connector - Add digital channels? - Add battery measurement - Move JTAG connector + Add resistor and capacitor values + bigger diodes footprint
APS6404L-3SQR-SN
0.5% tolerance
595-OPA4322AIPWR
CPU
SMD connector 200-TSM10302LDH
+ Fix TFT connector location + Fix TFT IMO selection + Fix BJT pintout + Fit BL resistor values. 50Ohm + Change OPAMP ADC and DAC IC with bigger BW + Add capacitors to ADC channels - Change schottky diodes to SOT23-3
ANALOG
POWER
+ VREG + Crystal + PSRAM + BL BJT + TSC + TFT + UART + TESTPOINTS
+ Change BL resistors to 27Ohm - Add schotty diodes in parallel
Thick Film Resistors 0.5% 10K Input impedance 667-ERJ-3RBD2701V 667-ERJ-3RBD4301V 667-ERJ-3RBD8201V Thick Film Resistors 0.5%. 100K Input impedance 667-ERJ-3RBD2702V 667-ERJ-3RBD8202V 667-ERJ-3RBD4302V
CPU MISC
IM[2:0] Interface Data Pin in Use 010 16-bit bus DB15:0
BATTERY
- Fix ADC noise issues.
TFT
595-OPA2322AIDGKR or 595-OPA2834IDGKR

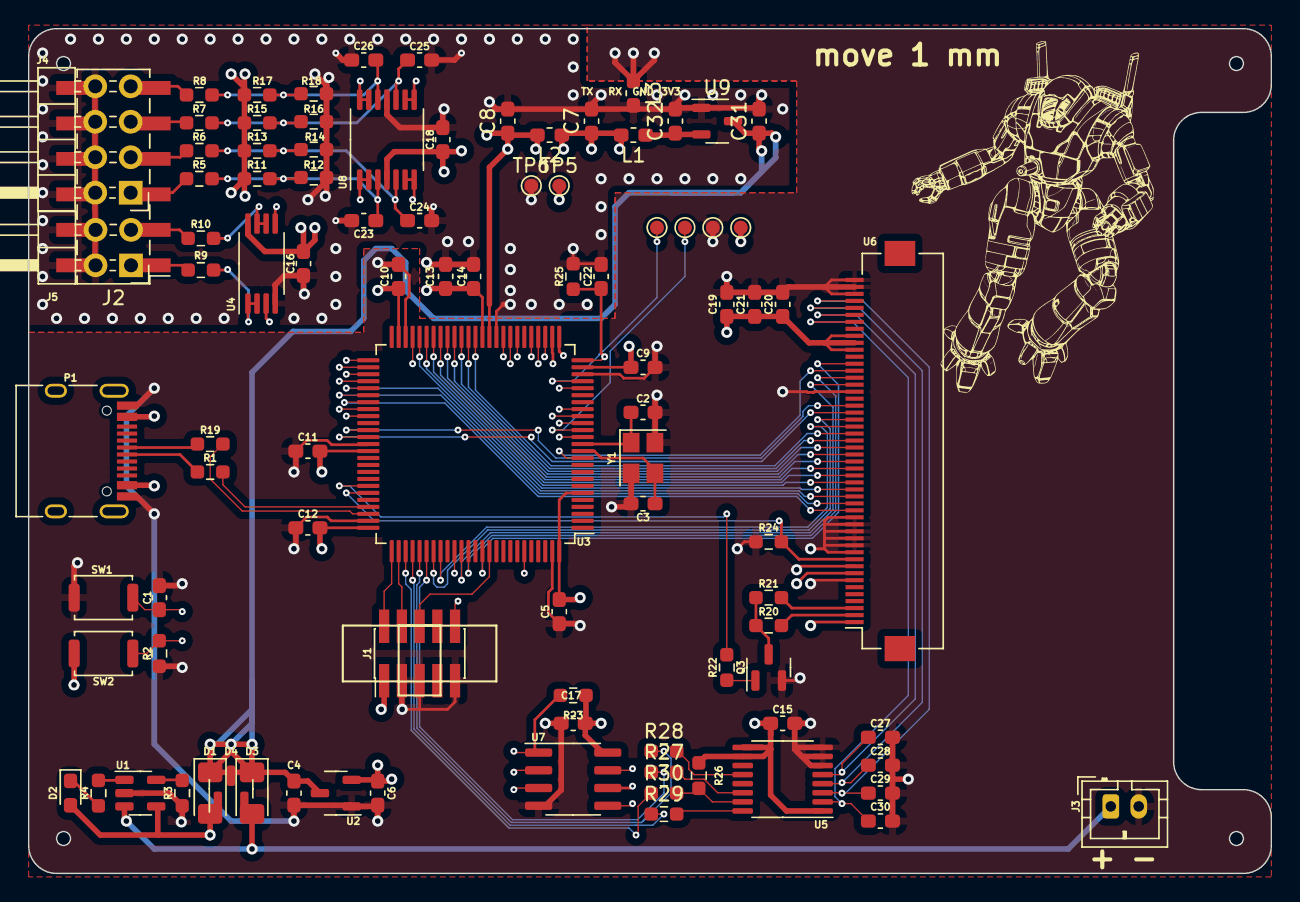
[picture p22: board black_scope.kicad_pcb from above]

Board: 4 copper layers, 89.0 x 60.5 mm, 94 parts (0 on the bottom side), 88 nets.

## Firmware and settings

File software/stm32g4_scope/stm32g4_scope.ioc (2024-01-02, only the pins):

Mcu.UserName=STM32G473VETx
PA1.Signal=OPAMP6_VINM0
PA11.Signal=USB_DM
PA12.Signal=USB_DP
PA13.Signal=SYS_JTMS-SWDIO
PA14.Signal=SYS_JTCK-SWCLK
PA15.GPIO_Label=TSC_nSS
PA15.Signal=GPIO_Output
PA3.Signal=OPAMP1_VINM0
PA4.Signal=COMP_DAC11_group
PA5.Signal=COMP_DAC12_group
PA6.Signal=COMP_DAC21_group
PA7.Signal=OPAMP1_VINP
PA8.GPIO_Label=LCD_BL
PA8.Signal=GPIO_Output
PA9.GPIO_Label=LCD_nRST
PA9.Signal=GPIO_Output
PB0.Signal=OPAMP3_VINP
PB10.Signal=QUADSPI1_CLK
PB13.Signal=OPAMP6_VINP
PB14.Signal=OPAMP5_VINP
PB15.Signal=OPAMP5_VINM0
PB2.Signal=OPAMP3_VINM0
PB3.Signal=SYS_JTDO-SWO
PC1.Signal=QUADSPI1_BK2_IO0
PC10.Signal=SPI3_SCK
PC11.Signal=SPI3_MISO
PC12.Signal=SPI3_MOSI
PC2.Signal=QUADSPI1_BK2_IO1
PC3.Signal=QUADSPI1_BK2_IO2
PC4.Signal=QUADSPI1_BK2_IO3
PD0.Signal=FMC_D2
PD1.Signal=FMC_D3
PD10.Signal=FMC_D15
PD14.Signal=FMC_D0
PD15.Signal=FMC_D1
PD3.Signal=QUADSPI1_BK2_NCS
PD4.Signal=FMC_NOE
PD5.Signal=FMC_NWE
PD7.Signal=FMC_NE1
PD8.Signal=FMC_D13
PD9.Signal=FMC_D14
PE10.Signal=FMC_D7
PE11.Signal=FMC_D8
PE12.Signal=FMC_D9
PE13.Signal=FMC_D10
PE14.Signal=FMC_D11
PE15.Signal=FMC_D12
PE7.Signal=FMC_D4
PE8.Signal=FMC_D5
PE9.Signal=FMC_D6
PF0-OSC_IN.Signal=RCC_OSC_IN
PF1-OSC_OUT.Signal=RCC_OSC_OUT
PF10.Signal=FMC_A0

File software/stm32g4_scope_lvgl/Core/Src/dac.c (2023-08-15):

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
/* Includes ------------------------------------------------------------------*/
#include "dac.h"

DAC_HandleTypeDef hdac1;
DAC_HandleTypeDef hdac2;
DMA_HandleTypeDef hdma_dac1_ch1;
DMA_HandleTypeDef hdma_dac1_ch2;

/* DAC1 init function */
void MX_DAC1_Init(void)
{

  DAC_ChannelConfTypeDef sConfig = {0};

  /** DAC Initialization
  */
  hdac1.Instance = DAC1;
  if (HAL_DAC_Init(&hdac1) != HAL_OK)
  {
    Error_Handler();
  }

  /** DAC channel OUT1 config
  */
  sConfig.DAC_HighFrequency = DAC_HIGH_FREQUENCY_INTERFACE_MODE_AUTOMATIC;
  sConfig.DAC_DMADoubleDataMode = DISABLE;
  sConfig.DAC_SignedFormat = DISABLE;
  sConfig.DAC_SampleAndHold = DAC_SAMPLEANDHOLD_DISABLE;
  sConfig.DAC_Trigger = DAC_TRIGGER_T4_TRGO;
  sConfig.DAC_Trigger2 = DAC_TRIGGER_NONE;
  sConfig.DAC_OutputBuffer = DAC_OUTPUTBUFFER_ENABLE;
  sConfig.DAC_ConnectOnChipPeripheral = DAC_CHIPCONNECT_EXTERNAL;
  sConfig.DAC_UserTrimming = DAC_TRIMMING_FACTORY;
  if (HAL_DAC_ConfigChannel(&hdac1, &sConfig, DAC_CHANNEL_1) != HAL_OK)
  {
    Error_Handler();
  }

  /** DAC channel OUT2 config
  */
  sConfig.DAC_Trigger = DAC_TRIGGER_T6_TRGO;
  if (HAL_DAC_ConfigChannel(&hdac1, &sConfig, DAC_CHANNEL_2) != HAL_OK)
  {
    Error_Handler();
  }
}
/* DAC2 init function */
void MX_DAC2_Init(void)
{

  DAC_ChannelConfTypeDef sConfig = {0};

  /** DAC Initialization
  */
  hdac2.Instance = DAC2;
  if (HAL_DAC_Init(&hdac2) != HAL_OK)
  {
    Error_Handler();
  }

  /** DAC channel OUT1 config
  */
  sConfig.DAC_HighFrequency = DAC_HIGH_FREQUENCY_INTERFACE_MODE_AUTOMATIC;
  sConfig.DAC_DMADoubleDataMode = DISABLE;
  sConfig.DAC_SignedFormat = DISABLE;
  sConfig.DAC_SampleAndHold = DAC_SAMPLEANDHOLD_DISABLE;
  sConfig.DAC_Trigger = DAC_TRIGGER_NONE;
  sConfig.DAC_Trigger2 = DAC_TRIGGER_NONE;
  sConfig.DAC_OutputBuffer = DAC_OUTPUTBUFFER_ENABLE;
  sConfig.DAC_ConnectOnChipPeripheral = DAC_CHIPCONNECT_EXTERNAL;
  sConfig.DAC_UserTrimming = DAC_TRIMMING_FACTORY;
  if (HAL_DAC_ConfigChannel(&hdac2, &sConfig, DAC_CHANNEL_1) != HAL_OK)
  {
    Error_Handler();
  }
}

void HAL_DAC_MspInit(DAC_HandleTypeDef* dacHandle)
{

  GPIO_InitTypeDef GPIO_InitStruct = {0};
  if(dacHandle->Instance==DAC1)
  {
    /* DAC1 clock enable */
    __HAL_RCC_DAC1_CLK_ENABLE();

    __HAL_RCC_GPIOA_CLK_ENABLE();
    /**DAC1 GPIO Configuration
    PA4     ------> DAC1_OUT1
    PA5     ------> DAC1_OUT2
    */
    GPIO_InitStruct.Pin = GPIO_PIN_4|GPIO_PIN_5;
    GPIO_InitStruct.Mode = GPIO_MODE_ANALOG;
    GPIO_InitStruct.Pull = GPIO_NOPULL;
    HAL_GPIO_Init(GPIOA, &GPIO_InitStruct);

    /* DAC1 DMA Init */
    /* DAC1_CH1 Init */
    hdma_dac1_ch1.Instance = DMA2_Channel1;
    hdma_dac1_ch1.Init.Request = DMA_REQUEST_DAC1_CHANNEL1;
    hdma_dac1_ch1.Init.Direction = DMA_MEMORY_TO_PERIPH;
    hdma_dac1_ch1.Init.PeriphInc = DMA_PINC_DISABLE;
    hdma_dac1_ch1.Init.MemInc = DMA_MINC_ENABLE;
    hdma_dac1_ch1.Init.PeriphDataAlignment = DMA_PDATAALIGN_WORD;
    hdma_dac1_ch1.Init.MemDataAlignment = DMA_MDATAALIGN_HALFWORD;
    hdma_dac1_ch1.Init.Mode = DMA_CIRCULAR;
    hdma_dac1_ch1.Init.Priority = DMA_PRIORITY_LOW;
    if (HAL_DMA_Init(&hdma_dac1_ch1) != HAL_OK)
    {
      Error_Handler();
    }

    __HAL_LINKDMA(dacHandle,DMA_Handle1,hdma_dac1_ch1);

    /* DAC1_CH2 Init */
    hdma_dac1_ch2.Instance = DMA2_Channel2;
    hdma_dac1_ch2.Init.Request = DMA_REQUEST_DAC1_CHANNEL2;
    hdma_dac1_ch2.Init.Direction = DMA_MEMORY_TO_PERIPH;
    hdma_dac1_ch2.Init.PeriphInc = DMA_PINC_DISABLE;
    hdma_dac1_ch2.Init.MemInc = DMA_MINC_ENABLE;
    hdma_dac1_ch2.Init.PeriphDataAlignment = DMA_PDATAALIGN_WORD;
    hdma_dac1_ch2.Init.MemDataAlignment = DMA_MDATAALIGN_HALFWORD;
    hdma_dac1_ch2.Init.Mode = DMA_CIRCULAR;
    hdma_dac1_ch2.Init.Priority = DMA_PRIORITY_LOW;
    if (HAL_DMA_Init(&hdma_dac1_ch2) != HAL_OK)
    {
      Error_Handler();
    }

    __HAL_LINKDMA(dacHandle,DMA_Handle2,hdma_dac1_ch2);

  }
  else if(dacHandle->Instance==DAC2)
  {
    /* DAC2 clock enable */
    __HAL_RCC_DAC2_CLK_ENABLE();

    __HAL_RCC_GPIOA_CLK_ENABLE();
    /**DAC2 GPIO Configuration
    PA6     ------> DAC2_OUT1
    */
    GPIO_InitStruct.Pin = GPIO_PIN_6;
    GPIO_InitStruct.Mode = GPIO_MODE_ANALOG;
    GPIO_InitStruct.Pull = GPIO_NOPULL;
    HAL_GPIO_Init(GPIOA, &GPIO_InitStruct);

  }
}

void HAL_DAC_MspDeInit(DAC_HandleTypeDef* dacHandle)
{

  if(dacHandle->Instance==DAC1)
  {
    /* Peripheral clock disable */
    __HAL_RCC_DAC1_CLK_DISABLE();

    /**DAC1 GPIO Configuration
    PA4     ------> DAC1_OUT1
    PA5     ------> DAC1_OUT2
    */
    HAL_GPIO_DeInit(GPIOA, GPIO_PIN_4|GPIO_PIN_5);

    /* DAC1 DMA DeInit */
    HAL_DMA_DeInit(dacHandle->DMA_Handle1);
    HAL_DMA_DeInit(dacHandle->DMA_Handle2);
  }
  else if(dacHandle->Instance==DAC2)
  {
    /* Peripheral clock disable */
    __HAL_RCC_DAC2_CLK_DISABLE();

    /**DAC2 GPIO Configuration
    PA6     ------> DAC2_OUT1
    */
    HAL_GPIO_DeInit(GPIOA, GPIO_PIN_6);

  }
}



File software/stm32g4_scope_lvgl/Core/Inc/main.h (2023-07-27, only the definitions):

#define LCD_BL_Pin GPIO_PIN_8
#define LCD_BL_GPIO_Port GPIOA
#define LCD_nRST_Pin GPIO_PIN_9
#define LCD_nRST_GPIO_Port GPIOA
#define TSC_nSS_Pin GPIO_PIN_15
#define TSC_nSS_GPIO_Port GPIOA

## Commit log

2023-06-03 - Initial commit
    [black_scope-B_Cu.gbr, black_scope-B_Mask.gbr, black_scope-B_Paste.gbr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]
2023-06-29 - Added images
    [black_scope.kicad_pcb, black_scope.kicad_sch]
2023-07-16 - Update fw
    [black_scope.kicad_sch]
2023-07-18 - Update framebuffer
2023-07-20 - Fix PCB issues - Add datasheets
    [black_scope.kicad_pcb, black_scope.kicad_sch]
2023-07-20 - Gerber files v2
    [black_scope-B_Cu.gbr, black_scope-B_Mask.gbr, black_scope-B_Paste.gbr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]
2023-07-21 - Improve FPS
    [black_scope.kicad_sch]
2023-07-23 - Refactor fonts and framebuf
2023-07-28 - Added PSRAM with QSPI - Added nuklear theme - Added 3d case generated with YAPP_Box
    [black_scope.scad]
2023-07-29 - Change QUAD_SPI pins to hig speed - Added opamp calibration - Handle opamps from UI - Handle offset from UI - Clamp x and y to max and min in LCD set pixel - Add function to draw adc data
2023-07-30 - Add draw_grid function - Use set window in the LCD - Move TSC as a separate task - Add low pass filter to the TSC and a touch count threshold
2023-08-13 - Reduce buffers len to 512 and also timers one pulse values. - Move nuklear context as a global scope so it dont need to be in the freertos heap - FreeRTOS config, change configTOTAL_HEAP_SIZE from 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
    [black_scope.kicad_sch, black_scope.scad]
2023-08-15 - Added config file. Still removed from compiling. - Update freertos heap. Retain the same value. - Add tim6 so DAC CH1 and CH2 can work at different freqs. - In app_freertos Reduce tasks heap size R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
    - Set dac ch2 to use tim6
    - enable tim6
    - fonts: set array as const
    - Add scope functions to init hw
    - update wavegen to handle two timers
2023-08-15 - Temporally increase freertos stack to 32k (during code generation) - Enable irqs for ADC 3, 4, 5 - Enable AWD in ADC 3, 4, 5 - Update task heap size (during code generation) - add ui and scope init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
2023-08-17 - Update draw_buffers function to avoid erase previously drawn data. - Remove radius when drawing rectangles with nuklear - Initialize timer in OC mode. - Stop opamps before calibration - substract h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
    [app_freertos.c]
2023-08-22 - .cproject: Change optimizaion to -Ofast - app_freertos.c Add defines for ADC and DAC BUFFER_LEN Add new x0 parameter to nk_draw_fb Add new line_height variable Move UI to the right side of the scre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
    [app_freertos.c]
2023-08-23 - Came back to -O1 optimization - Added DMA1_ChannelX_CNDTR to get the trigger event - Remove CLAMP from lcd_set_window - Fix trigger for channels 3 and 4. It was the AWD OPAMP channels. - Added inte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
    [app_freertos.c]
2023-08-27 - first working version of the scope v2. only one channel. still some issues with horizontal freq.
    [app_freertos.c]
2023-09-02 - Add two new events when a menu or windows is collapsed. These events are handled in the ui and sent to the drivers. - The scope has initial support and is pending add to the wavegen.
2023-09-04 - Move the tsc code from the task to the driver.
2023-09-07 - Add tentative for freertos time stats - Added documentation to scope.c - Added documentation to scope.h - Added documentation to scope_draw.c - Added documentation to scope_draw.h - Reduce scope_wa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
    [app_freertos.c]
2024-01-02 Long time update
    [black_scope.csv, black_scope.kicad_pcb, black_scope.kicad_sch]
2024-01-09 - Remove wrong f401re folder - Add proper f401re folder with scope sw
    [main.h]

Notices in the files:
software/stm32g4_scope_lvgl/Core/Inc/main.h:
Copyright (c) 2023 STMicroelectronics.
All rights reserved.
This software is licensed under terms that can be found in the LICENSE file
